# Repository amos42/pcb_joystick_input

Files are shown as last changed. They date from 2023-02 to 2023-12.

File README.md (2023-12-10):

# Arcade Joystick 입력 장치

---

[74HC165를 사용한 Arcade Joystick 입력 보드 (DIP. 1P Ver.)](joystick_74hc165_input_1p/)
([README.md](joystick_74hc165_input_1p/README.md))

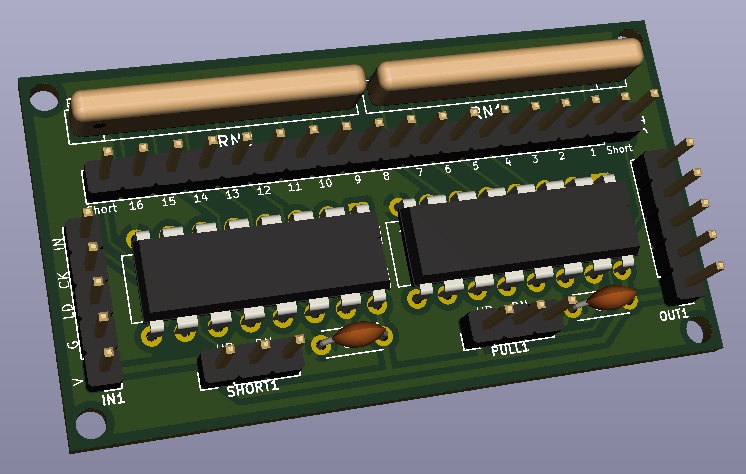
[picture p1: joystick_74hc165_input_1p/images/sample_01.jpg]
joystick-input (DIP Ver.)


---

[74HC165를 사용한 Arcade Joystick 입력 보드 (DIP. 2P Ver.)](joystick_74hc165_input/)
([README.md](joystick_74hc165_input/README.md))

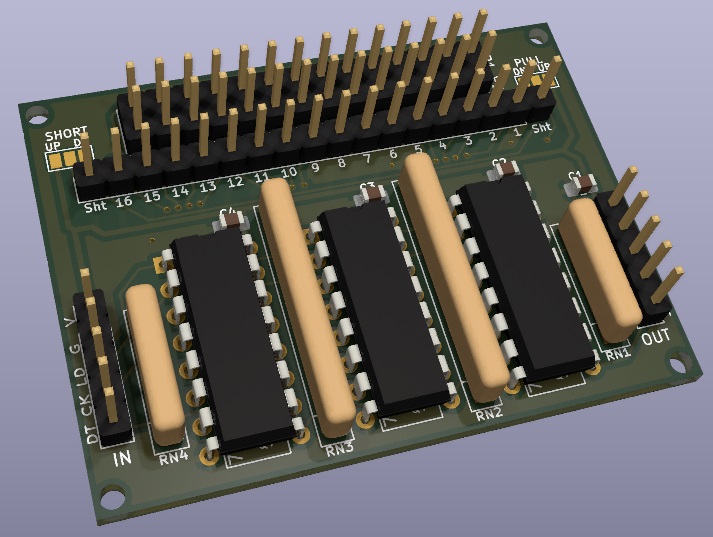
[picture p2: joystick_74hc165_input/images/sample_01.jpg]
joystick-input (DIP Ver.)


---

[74HC165를 사용한 Arcade Joystick 입력 보드 (SMD. 2P Ver.)](joystick_74hc165_input_smd/)
([README.md](joystick_74hc165_input_smd/README.md))

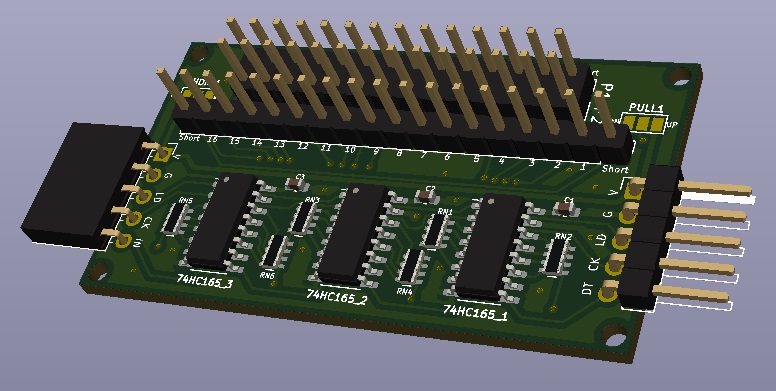
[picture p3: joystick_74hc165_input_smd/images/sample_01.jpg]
joystick-input (SMD Ver.)


---

[74HC165를 사용한 Arcade Joystick 입력 보드 (JST 커넥터. 2P Ver)](joystick_74hc165_input_jst/)
([README.md](joystick_74hc165_input_jst/README.md))

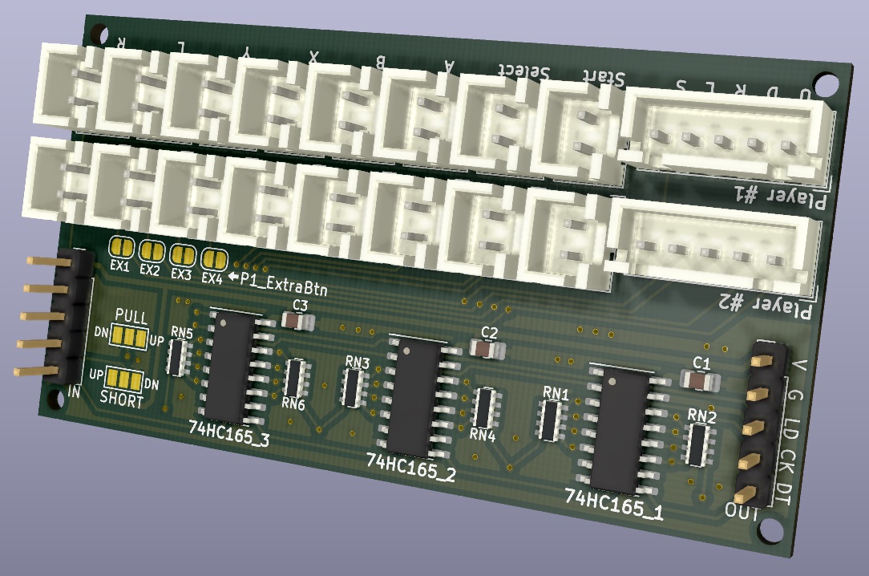
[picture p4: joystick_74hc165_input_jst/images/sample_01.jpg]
joystick-input (JST Ver.)


---

[Raspberry Pie GPIO 입력 모듈](joystick_gpio_input/)
([README.md](joystick_gpio_input/README.md))

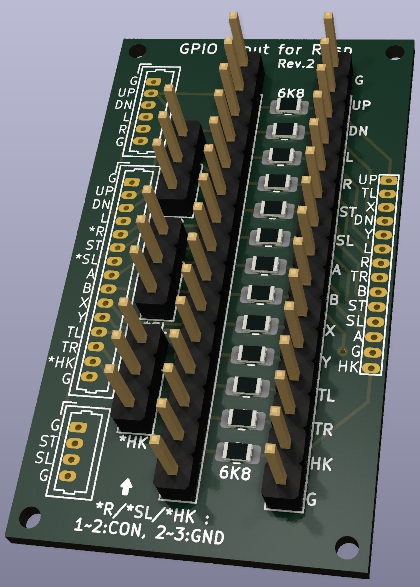
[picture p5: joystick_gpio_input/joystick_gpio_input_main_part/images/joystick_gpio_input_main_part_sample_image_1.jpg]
joystick_gpio_input (main part)


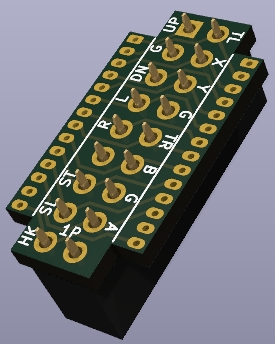
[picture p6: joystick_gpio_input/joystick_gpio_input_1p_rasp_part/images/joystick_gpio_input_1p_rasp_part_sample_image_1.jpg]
joystick_gpio_input (1p part)

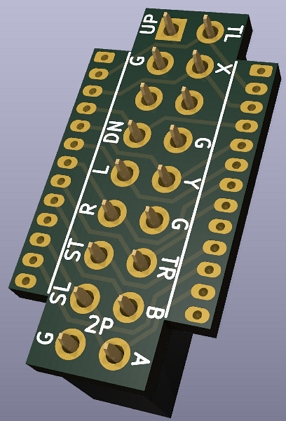
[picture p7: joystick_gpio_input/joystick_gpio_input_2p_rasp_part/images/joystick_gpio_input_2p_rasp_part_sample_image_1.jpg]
joystick_gpio_input (2p part)


---

[Arcade 입력 패널 Support 보드](arcade_input_panel_support/)
([README.md](arcade_input_panel_support/README.md))

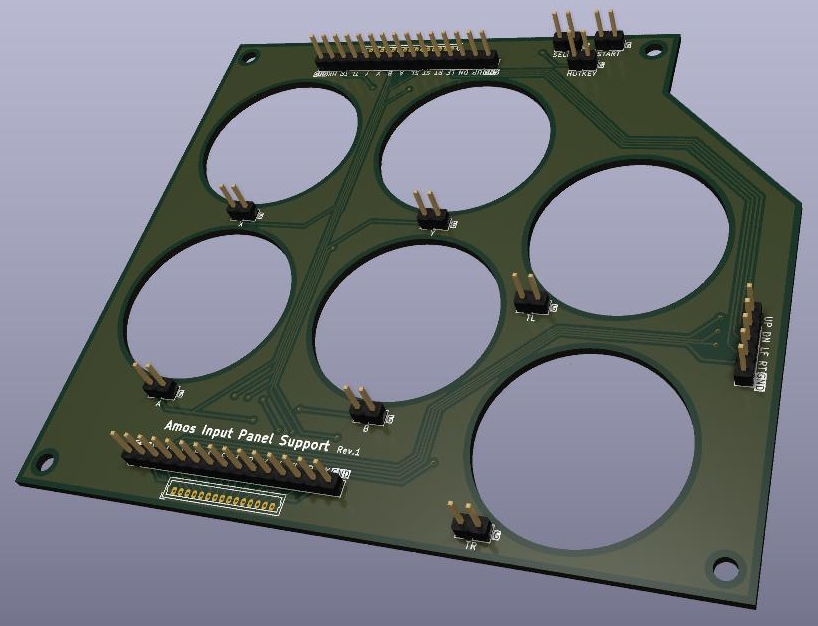
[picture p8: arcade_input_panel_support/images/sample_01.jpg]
Arcade 입력 패널 Support 보드


---

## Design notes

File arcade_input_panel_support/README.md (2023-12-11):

# Arcade Input Panel Support Board

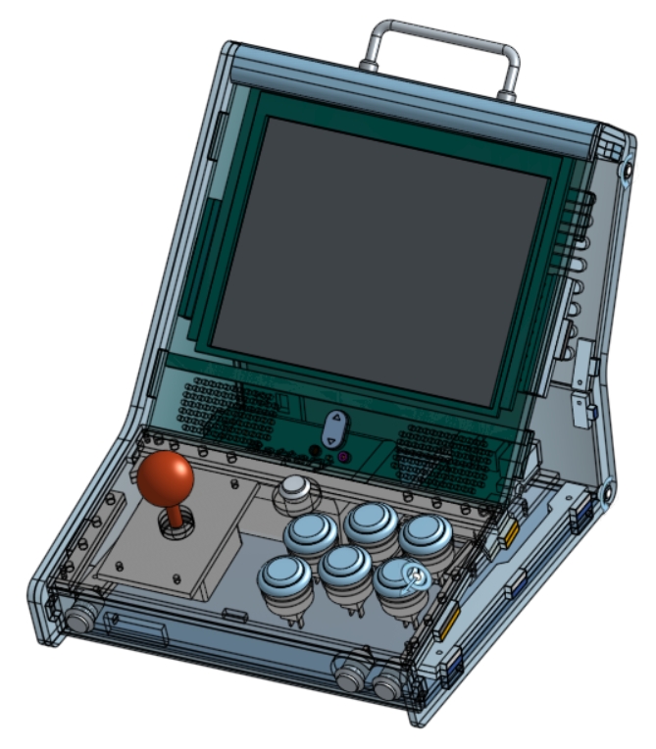
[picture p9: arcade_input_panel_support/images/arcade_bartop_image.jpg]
Bartop 게임기 이미지


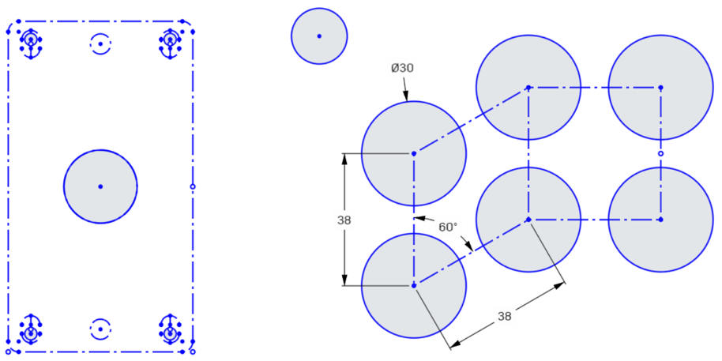
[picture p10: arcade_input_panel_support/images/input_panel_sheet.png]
입력 패널 도면


회로도

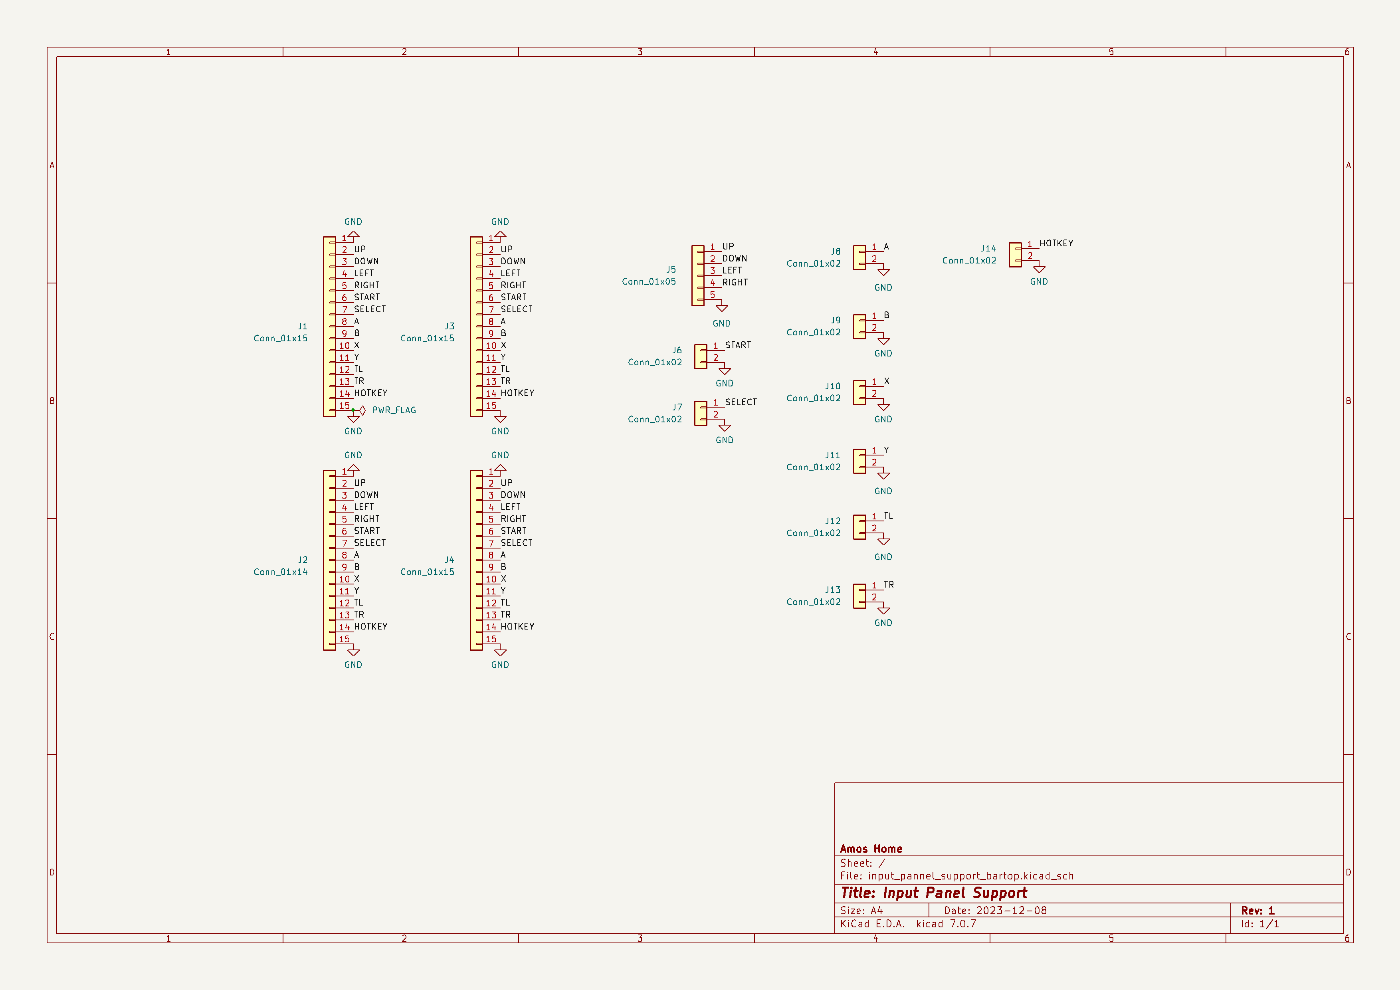
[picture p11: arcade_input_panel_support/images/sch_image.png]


PCB

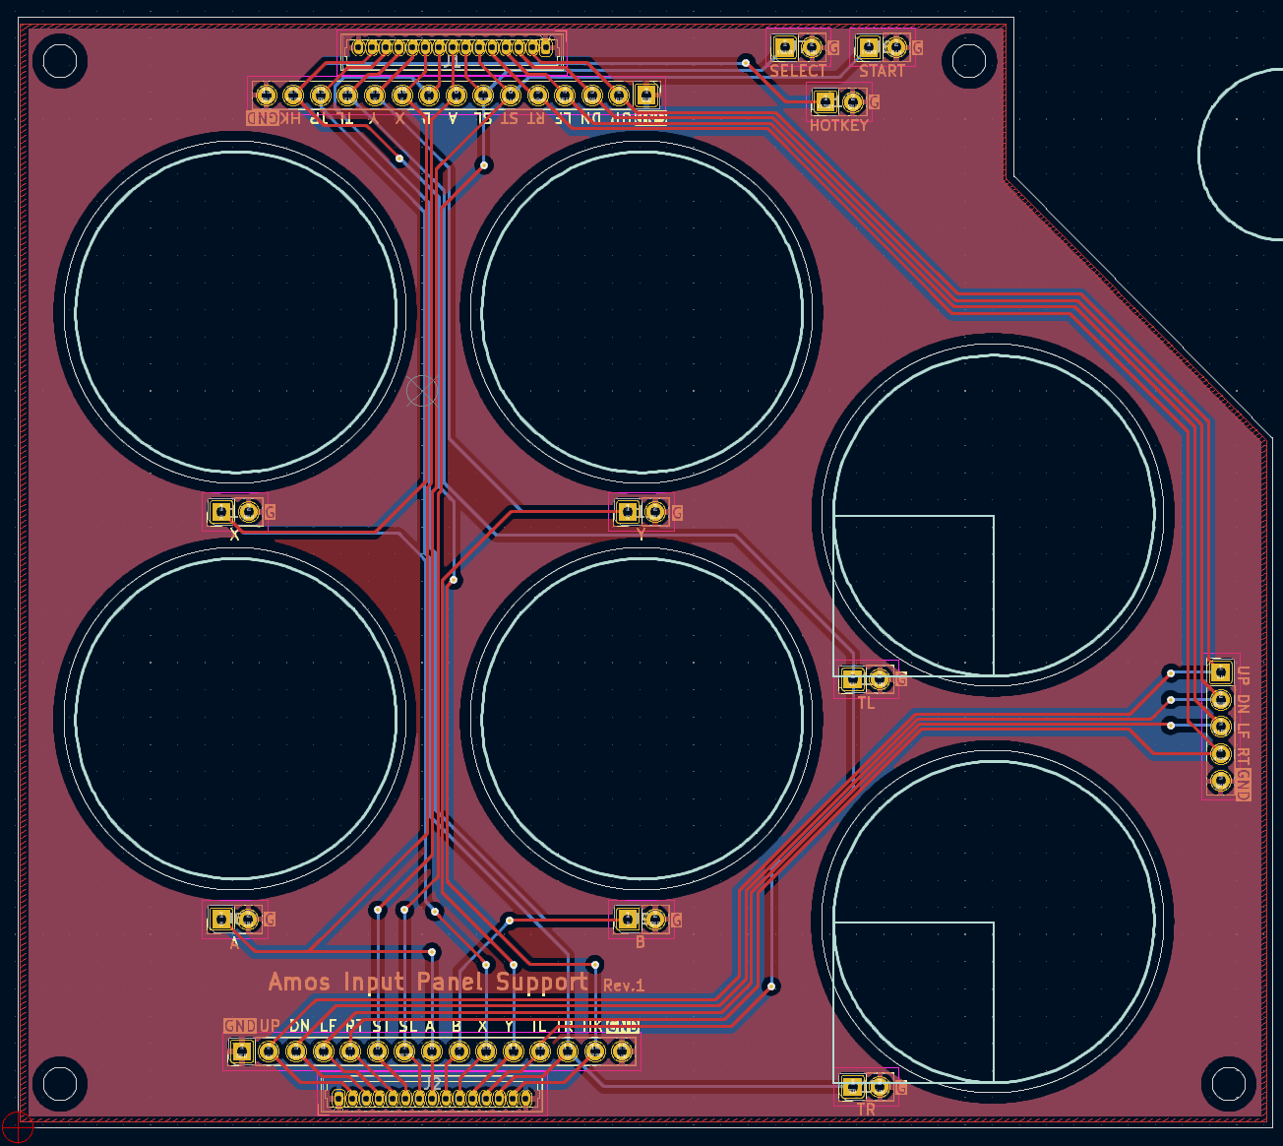
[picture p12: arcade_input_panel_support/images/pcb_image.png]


PCB 샘플 이미지

샘플 앞면

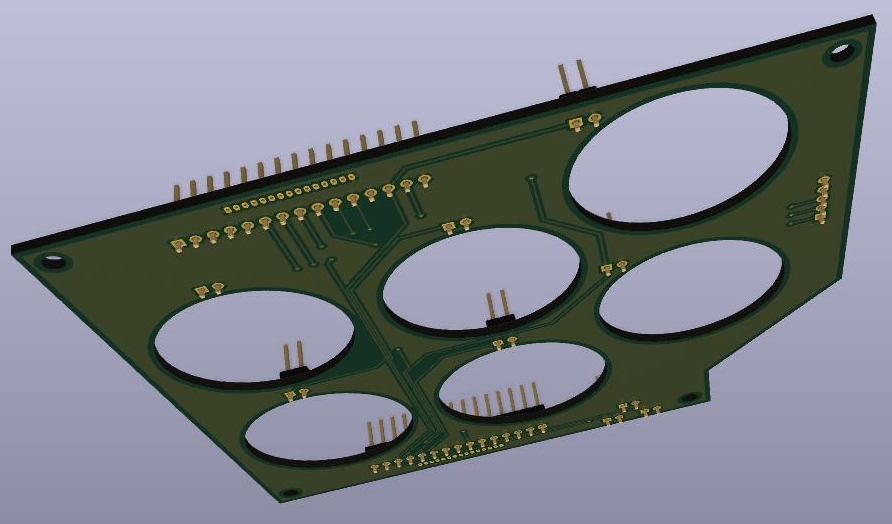
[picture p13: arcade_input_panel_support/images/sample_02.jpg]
샘플 뒷면


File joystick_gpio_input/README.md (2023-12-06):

# Raspberry Pie GPIO 입력 모듈

GPIO 보호 기능을 갖는 입력 모듈

---
am_joyin 혹은 mk_arcade_joystick_rpi의 GPIO 입력 맵을 기본으로 했다.

am_joyin 드라이버도 해당 GPIO 입력 맵과 호환된다.

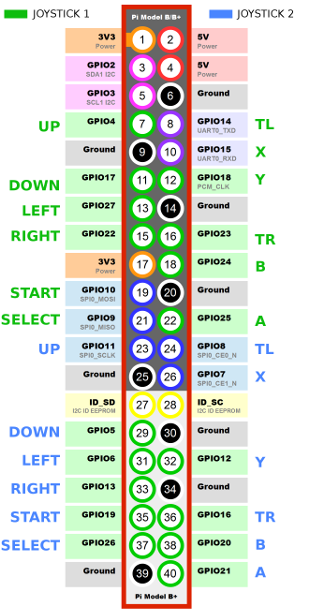
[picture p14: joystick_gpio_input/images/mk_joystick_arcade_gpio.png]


기본적으로는 1P를 기준으로 했으며, 2P 용으로는 GPIO를 모두 소진한다는 문제 때문에 2P는 optional 하게 추가 지원하도록 했다.

1P의 경우, HK를 GPIO11로 사용하게 했는데, 이를 원활히 사용하려면 am_joyin 드라이버를 쓰면 된다.

> ***info***  
am_joyin 링크 : [https://github.com/amos42/am_joyin](https://github.com/amos42/am_joyin)

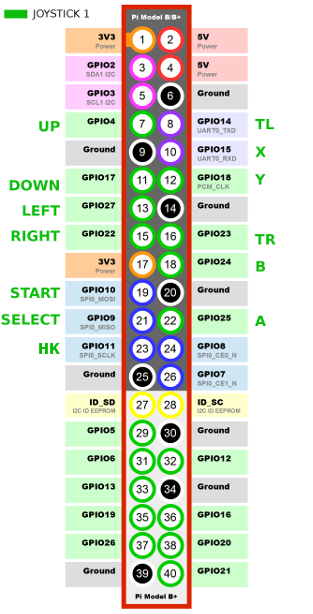
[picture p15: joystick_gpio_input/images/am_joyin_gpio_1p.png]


## 메인 파트

### 회로도

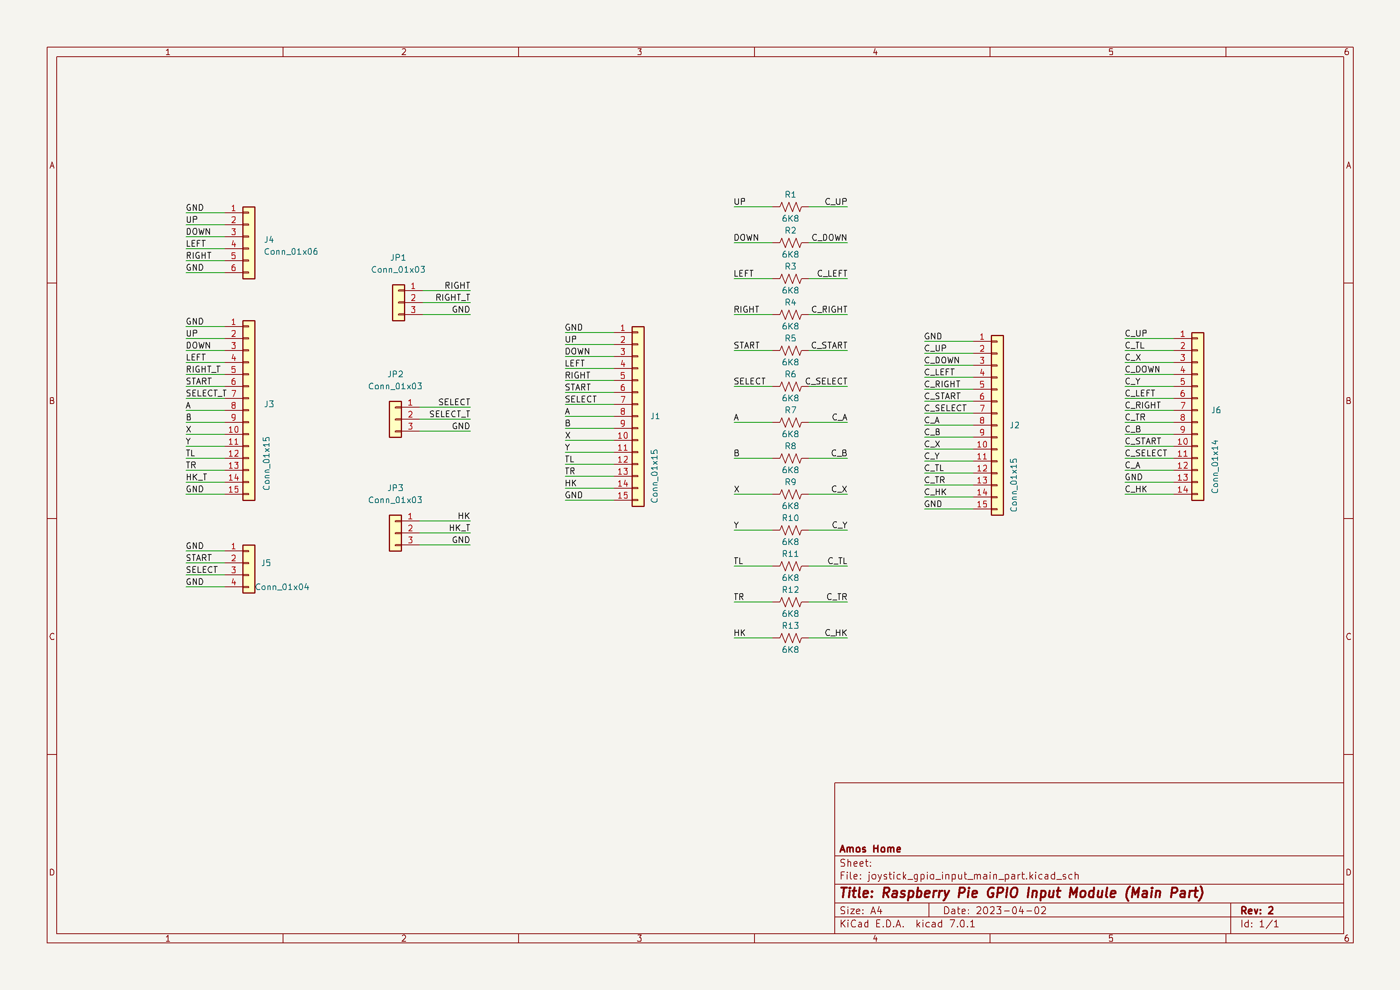
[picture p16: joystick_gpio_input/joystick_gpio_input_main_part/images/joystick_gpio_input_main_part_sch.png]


### PCB

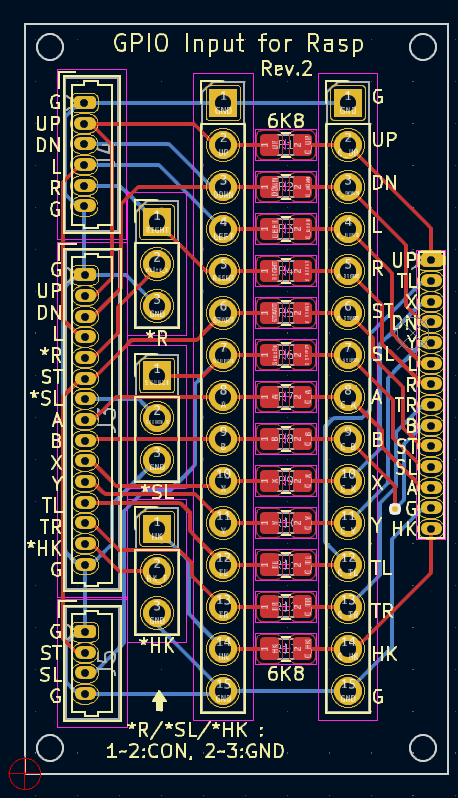
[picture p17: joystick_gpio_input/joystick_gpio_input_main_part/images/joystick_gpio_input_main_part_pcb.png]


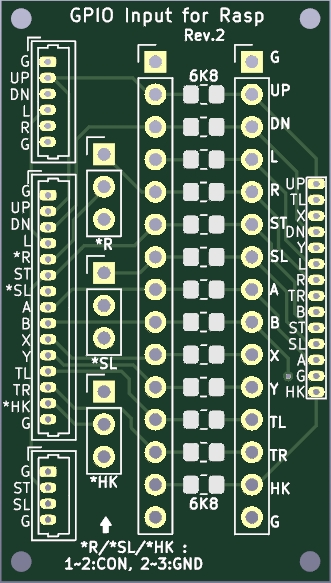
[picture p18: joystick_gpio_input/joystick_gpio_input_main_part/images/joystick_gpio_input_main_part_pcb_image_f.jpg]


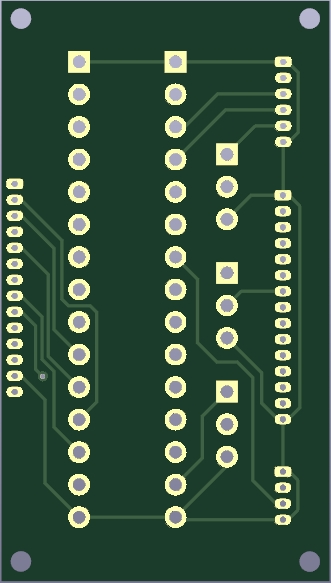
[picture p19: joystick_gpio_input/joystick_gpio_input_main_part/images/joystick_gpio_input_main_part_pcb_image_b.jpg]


### BOM

| Designator | Package | Quantity | Designation |
|---|---|---|---|
| R1~R13 | R_0805_2012Metric | 13 | 6.8K |

### 샘플 이미지

PCB

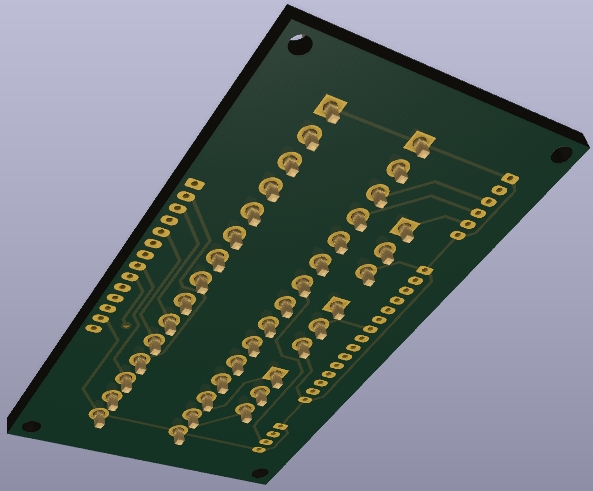
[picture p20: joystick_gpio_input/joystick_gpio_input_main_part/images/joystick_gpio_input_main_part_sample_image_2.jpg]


---

## Raspberry Pi Connector 1P 파트

### 회로도

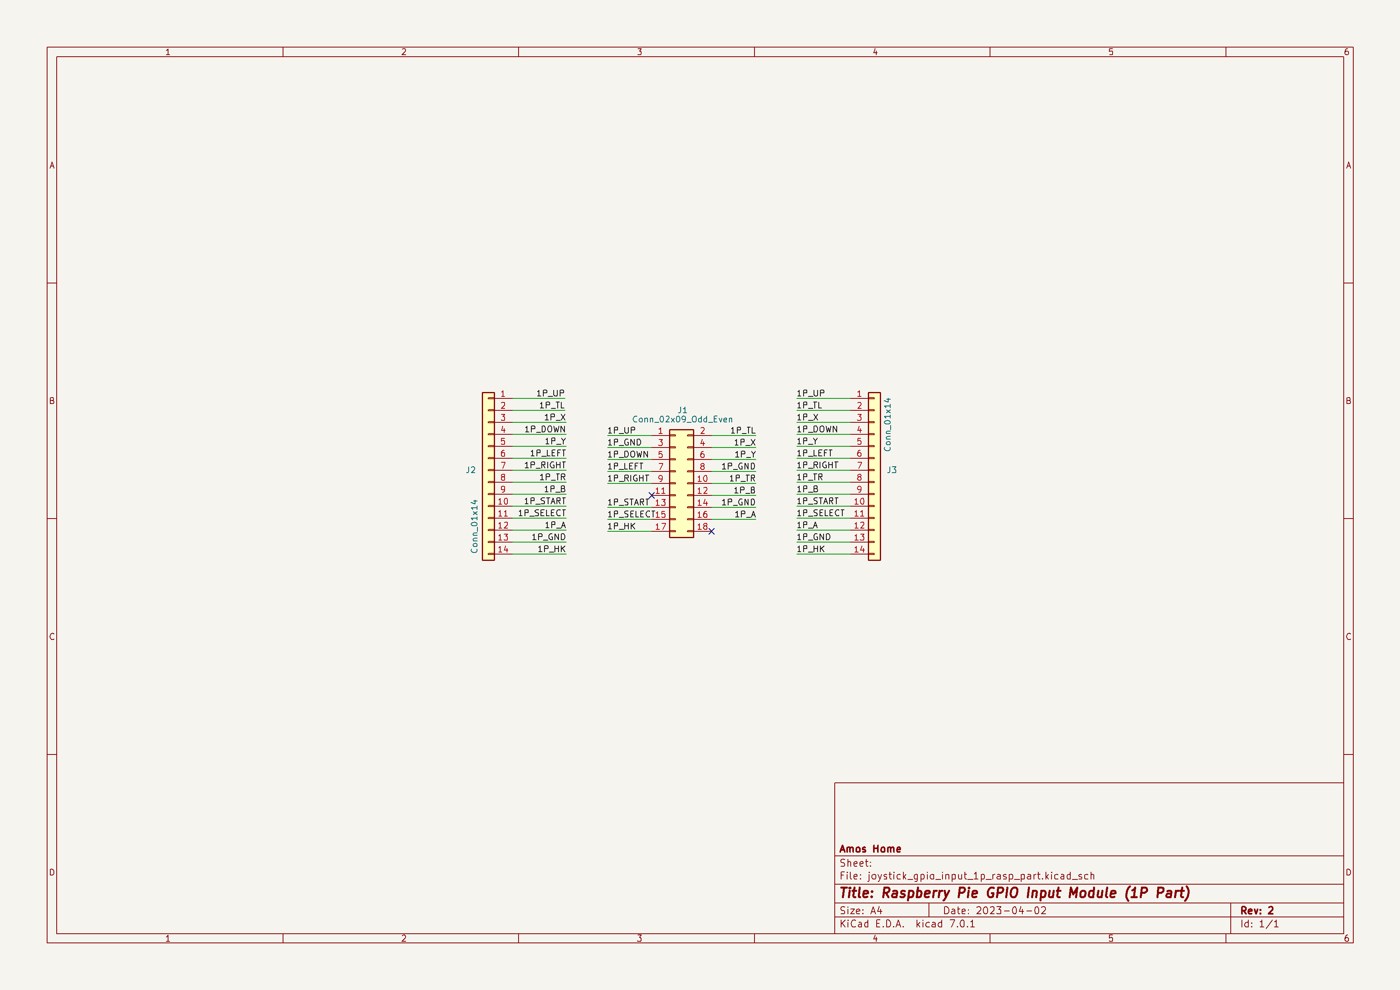
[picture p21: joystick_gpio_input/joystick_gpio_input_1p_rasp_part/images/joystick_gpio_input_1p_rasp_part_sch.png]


### PCB

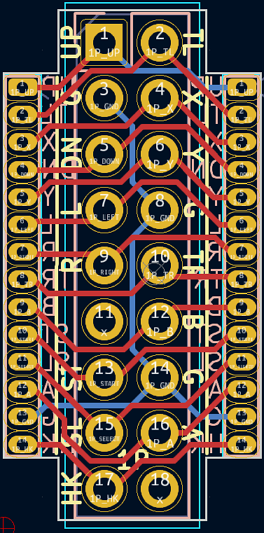
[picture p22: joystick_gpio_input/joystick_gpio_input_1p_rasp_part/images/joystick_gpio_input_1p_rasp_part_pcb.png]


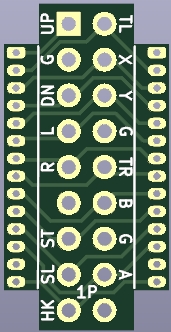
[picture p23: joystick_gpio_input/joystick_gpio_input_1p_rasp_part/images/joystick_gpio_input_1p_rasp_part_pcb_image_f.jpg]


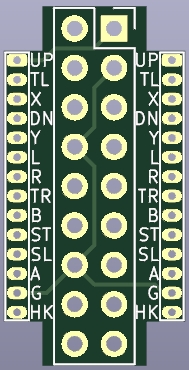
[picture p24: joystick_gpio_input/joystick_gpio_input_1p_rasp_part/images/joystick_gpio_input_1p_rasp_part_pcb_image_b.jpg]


### 샘플 이미지

PCB

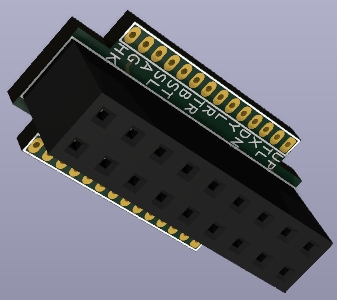
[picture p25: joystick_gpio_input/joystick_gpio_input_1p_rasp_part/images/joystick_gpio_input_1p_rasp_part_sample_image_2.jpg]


---

## Raspberry Pi Connector 2p 파트

### 회로도

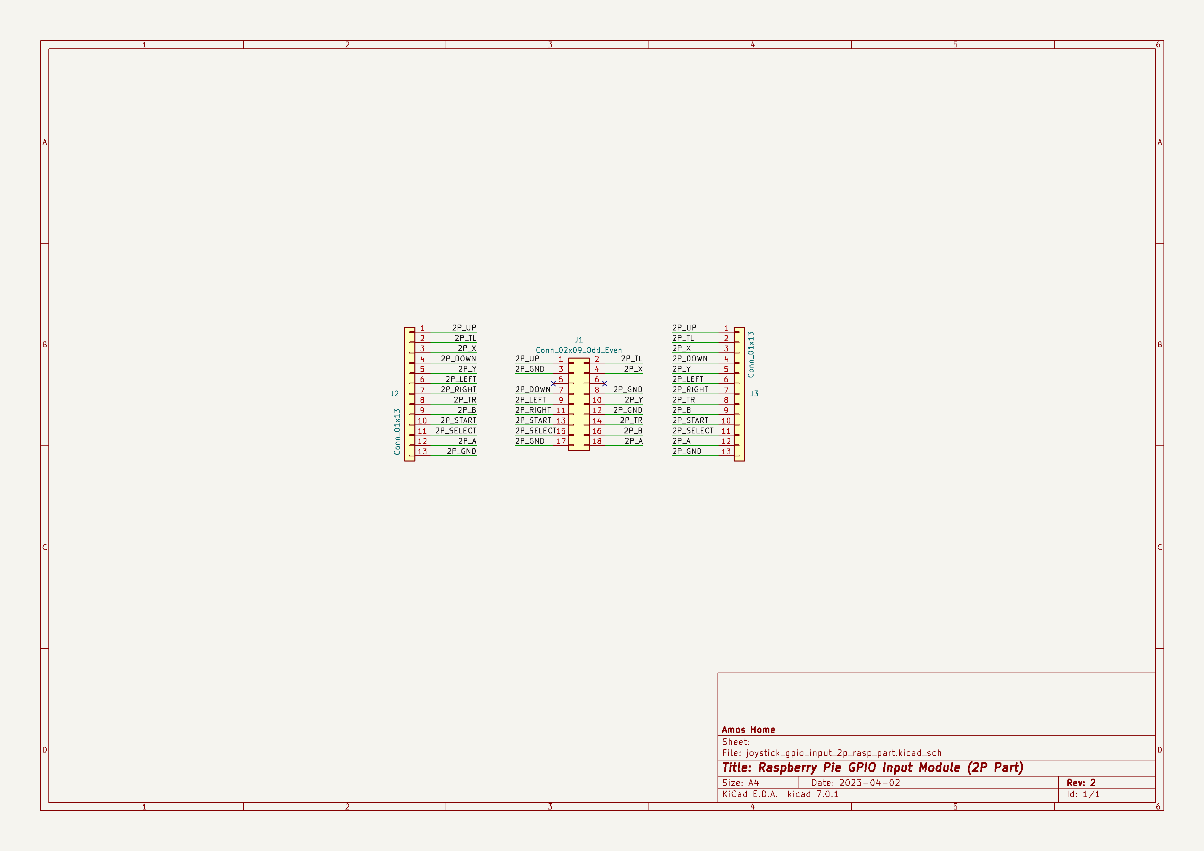
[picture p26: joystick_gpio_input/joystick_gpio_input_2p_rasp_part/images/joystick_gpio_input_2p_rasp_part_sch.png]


### PCB

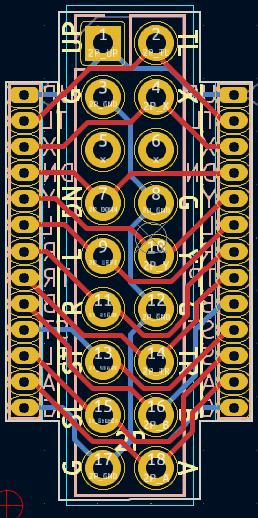
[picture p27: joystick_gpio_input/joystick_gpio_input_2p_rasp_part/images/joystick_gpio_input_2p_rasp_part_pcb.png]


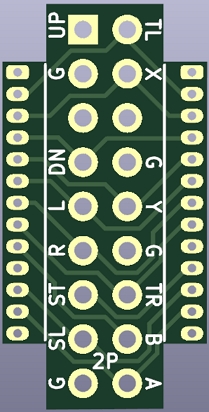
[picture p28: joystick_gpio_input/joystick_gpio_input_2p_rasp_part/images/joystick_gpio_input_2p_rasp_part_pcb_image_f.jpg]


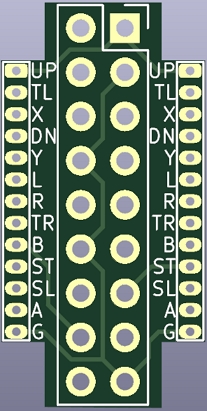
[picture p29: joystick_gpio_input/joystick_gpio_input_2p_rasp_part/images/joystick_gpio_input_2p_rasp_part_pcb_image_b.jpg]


### 샘플 이미지

PCB

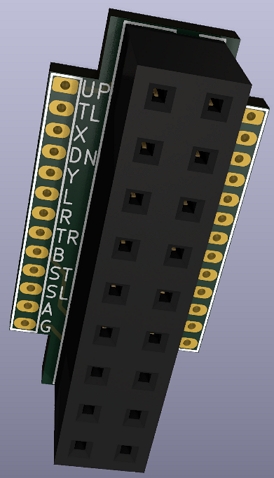
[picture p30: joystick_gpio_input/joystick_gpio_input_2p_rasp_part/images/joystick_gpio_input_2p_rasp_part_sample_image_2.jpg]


## 점퍼 세팅

커넥터 중 J3는 일부 핀을 점퍼 세팅으로 변경이 가능하다.

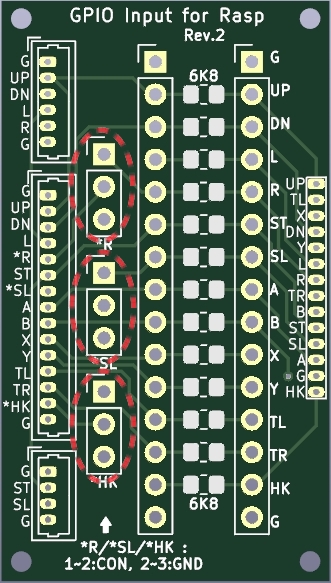
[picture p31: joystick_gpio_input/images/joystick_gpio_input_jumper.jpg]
샘플


* *R - 1-2 끊고 2-3 쇼트시, J3의 Right 핀이 GND로 쇼트
* *SL - 1-2 끊고 2-3 쇼트시, J3의 Select 핀이 GND로 쇼트
* *HK - 1-2 끊고 2-3 쇼트시, J3의 HotKey 핀이 GND로 쇼트

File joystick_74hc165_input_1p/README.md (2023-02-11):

# 74HC165를 이용한 Joystick (1P)입력 보드

회로도

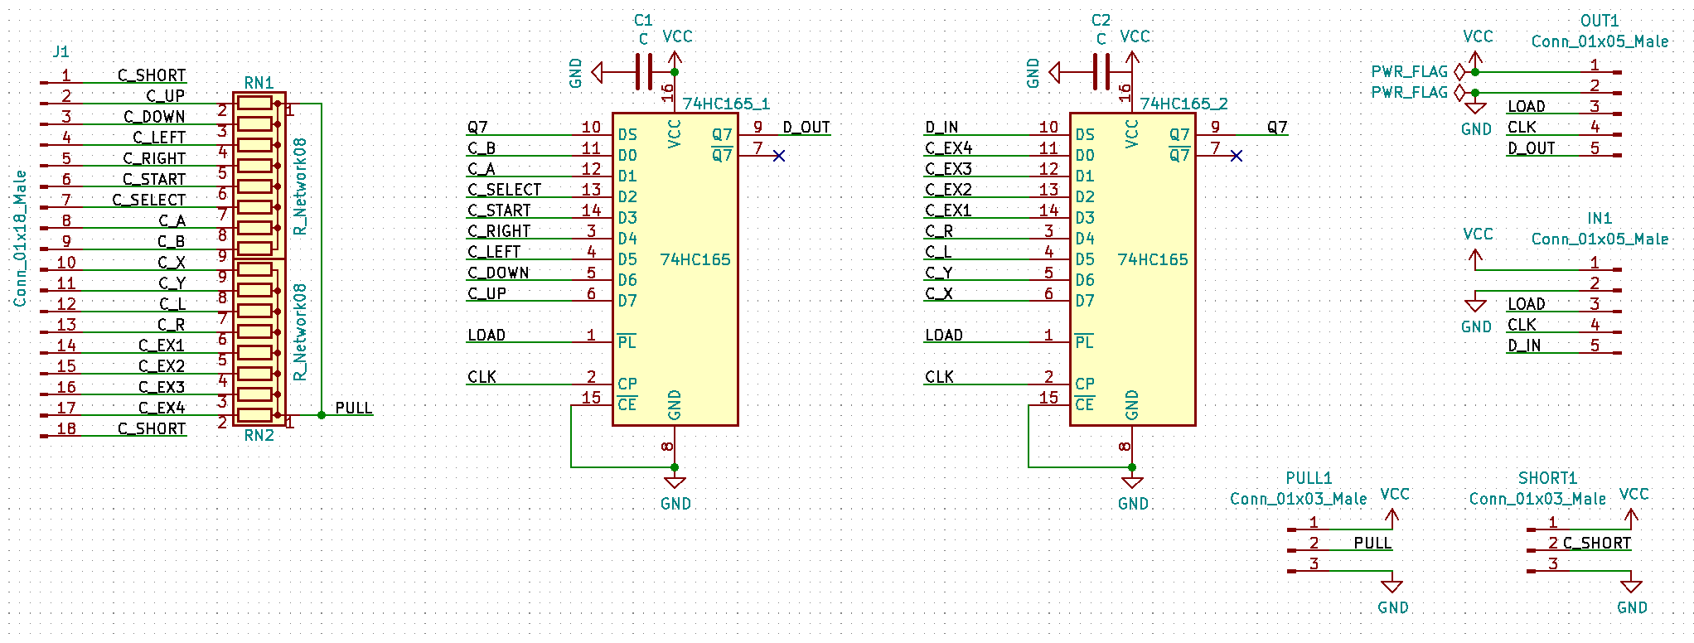
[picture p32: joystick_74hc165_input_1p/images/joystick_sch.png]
회로도


PCB 이미지 앞면

PCB

PCB 이미지 뒷면

PCB

샘플 이미지

샘플

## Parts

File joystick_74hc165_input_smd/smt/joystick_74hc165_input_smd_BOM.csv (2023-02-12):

Designator | Footprint | Comment
RN2,RN1,RN4,RN5,RN3,RN6 | R_Array_Concave_4x0603 | 10K | C29718
C1,C2,C3 | C_0805_2012Metric_Pad1.18x1.45mm_HandSolder | 100nF
74HC165_1,74HC165_2,74HC165_3 | SOIC-16_3.9x9.9mm_P1.27mm | 74HC165
C4 | C_0805_2012Metric_Pad1.18x1.45mm_HandSolder | 22nF

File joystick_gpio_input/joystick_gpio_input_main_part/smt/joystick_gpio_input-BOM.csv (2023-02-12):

Designator | Footprint | Comment
R10,R12,R13,R11,R4,R9,R5,R2,R8,R3,R7,R6,R1 | R_0805_2012Metric_Pad1.20x1.40mm_HandSolder | 6K8

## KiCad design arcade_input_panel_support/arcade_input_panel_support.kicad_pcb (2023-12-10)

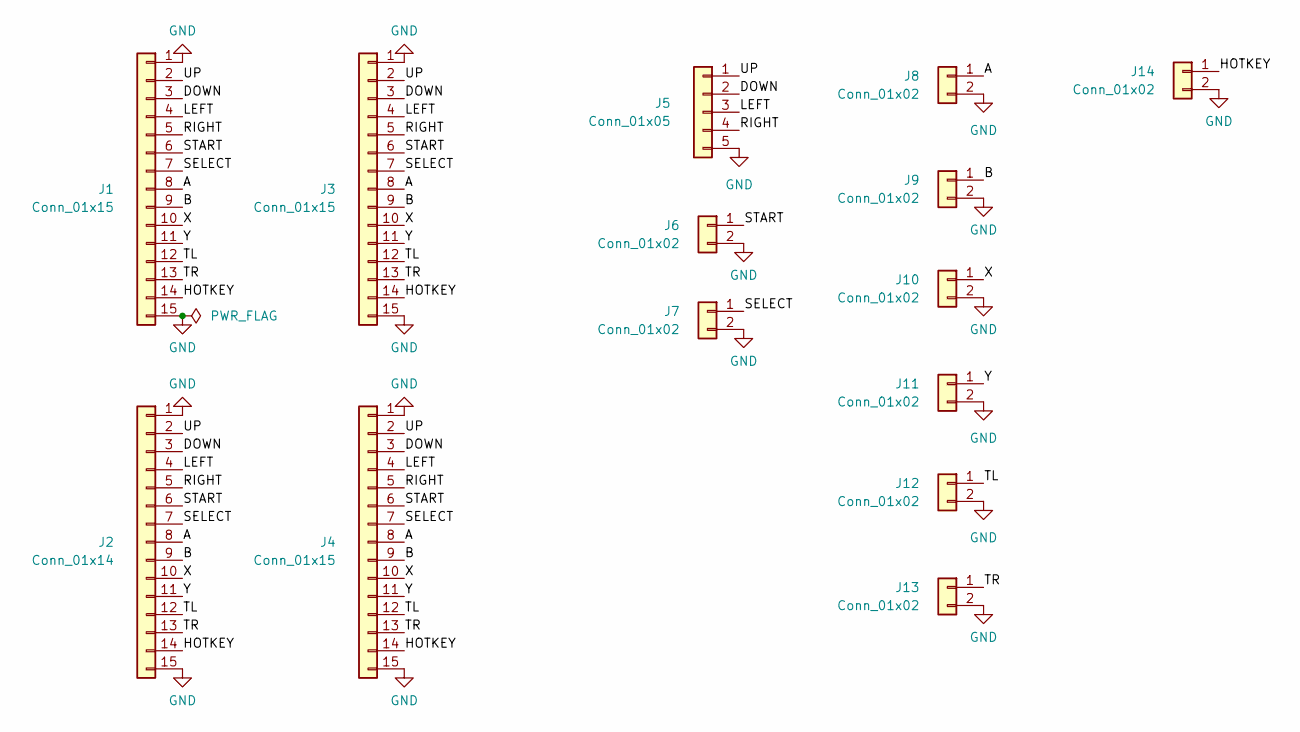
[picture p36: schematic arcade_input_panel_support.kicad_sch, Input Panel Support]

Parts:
J1: Conn_01x15; Molex_PicoBlade_53047-1510_1x15_P1.25mm_Vertical
J2: Conn_01x14; Molex_PicoBlade_53047-1510_1x15_P1.25mm_Vertical
J3, J4: Conn_01x15; PinHeader_1x15_P2.54mm_Vertical
J5: Conn_01x05; PinHeader_1x05_P2.54mm_Vertical
J6, J7, J8, J9, J10, J11, J12, J13, J14: Conn_01x02; PinHeader_1x02_P2.54mm_Vertical

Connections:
/A: J1.8, J2.8, J3.8, J4.8, J8.1
/B: J1.9, J2.9, J3.9, J4.9, J9.1
/DOWN: J1.3, J2.3, J3.3, J4.3, J5.2
/HOTKEY: J1.14, J2.14, J3.14, J4.14, J14.1
/LEFT: J1.4, J2.4, J3.4, J4.4, J5.3
/RIGHT: J1.5, J2.5, J3.5, J4.5, J5.4
/SELECT: J1.7, J2.7, J3.7, J4.7, J7.1
/START: J1.6, J2.6, J3.6, J4.6, J6.1
/TL: J1.12, J2.12, J3.12, J4.12, J12.1
/TR: J1.13, J2.13, J3.13, J4.13, J13.1
/UP: J1.2, J2.2, J3.2, J4.2, J5.1
/X: J1.10, J2.10, J3.10, J4.10, J10.1
/Y: J1.11, J2.11, J3.11, J4.11, J11.1
GND: J1.1, J1.15, J2.1, J2.15, J3.1, J3.15, J4.1, J4.15, J5.5, J6.2, J7.2, J8.2, J9.2, J10.2, J11.2, J12.2, J13.2, J14.2

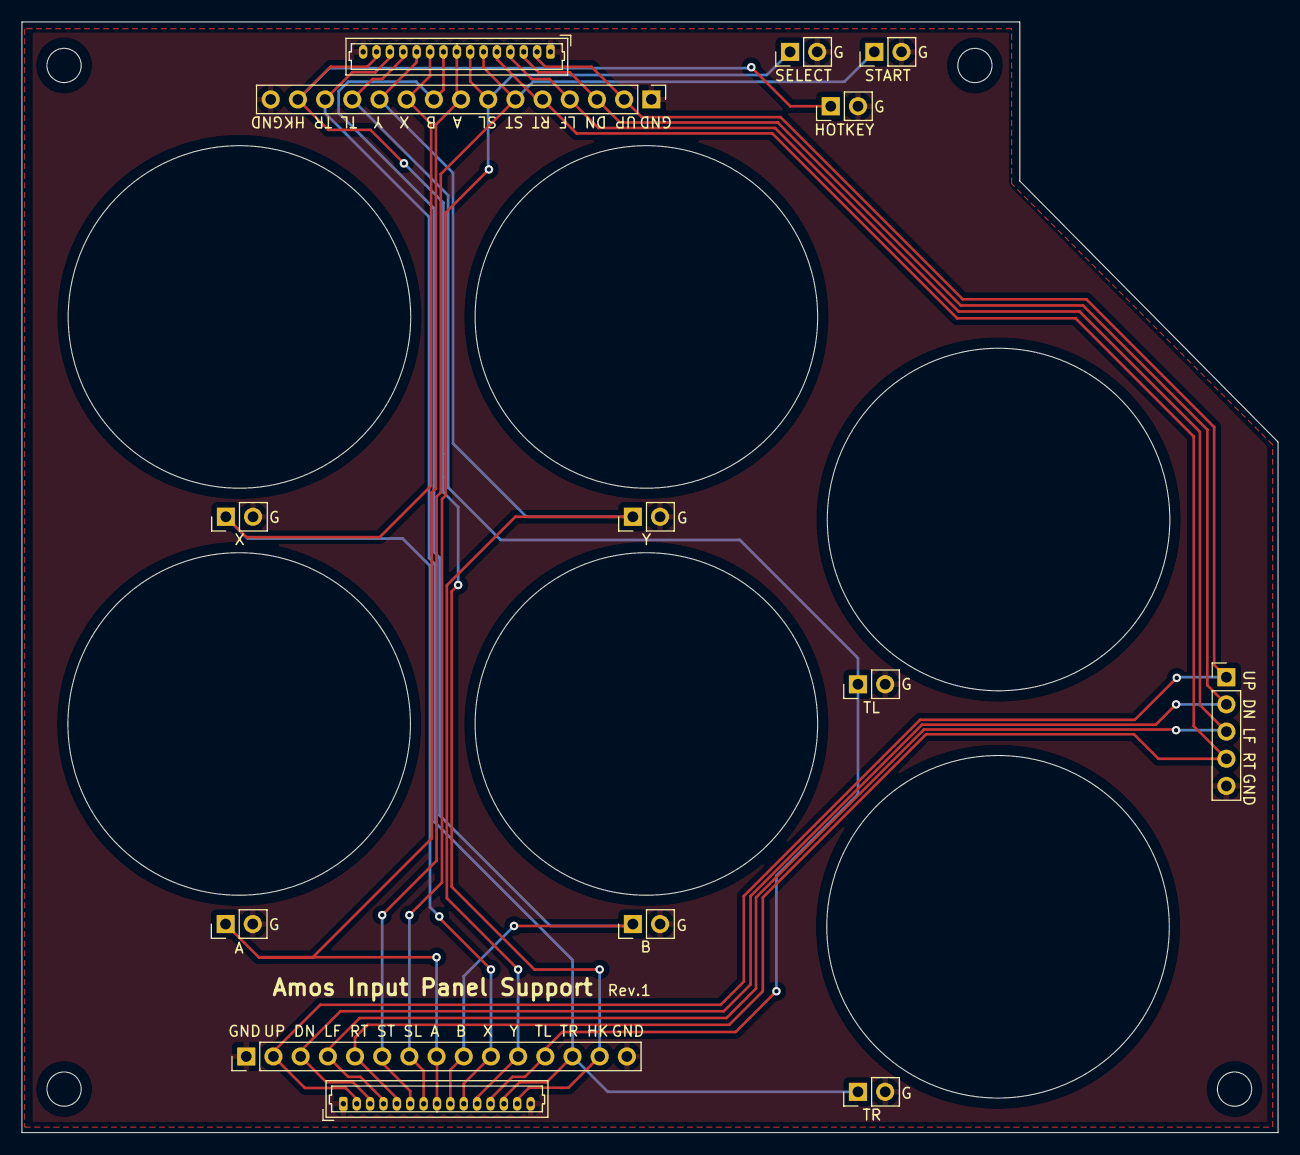
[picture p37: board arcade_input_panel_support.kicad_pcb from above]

Board: 2 copper layers, 117.3 x 103.8 mm, 14 parts (0 on the bottom side), 14 nets.

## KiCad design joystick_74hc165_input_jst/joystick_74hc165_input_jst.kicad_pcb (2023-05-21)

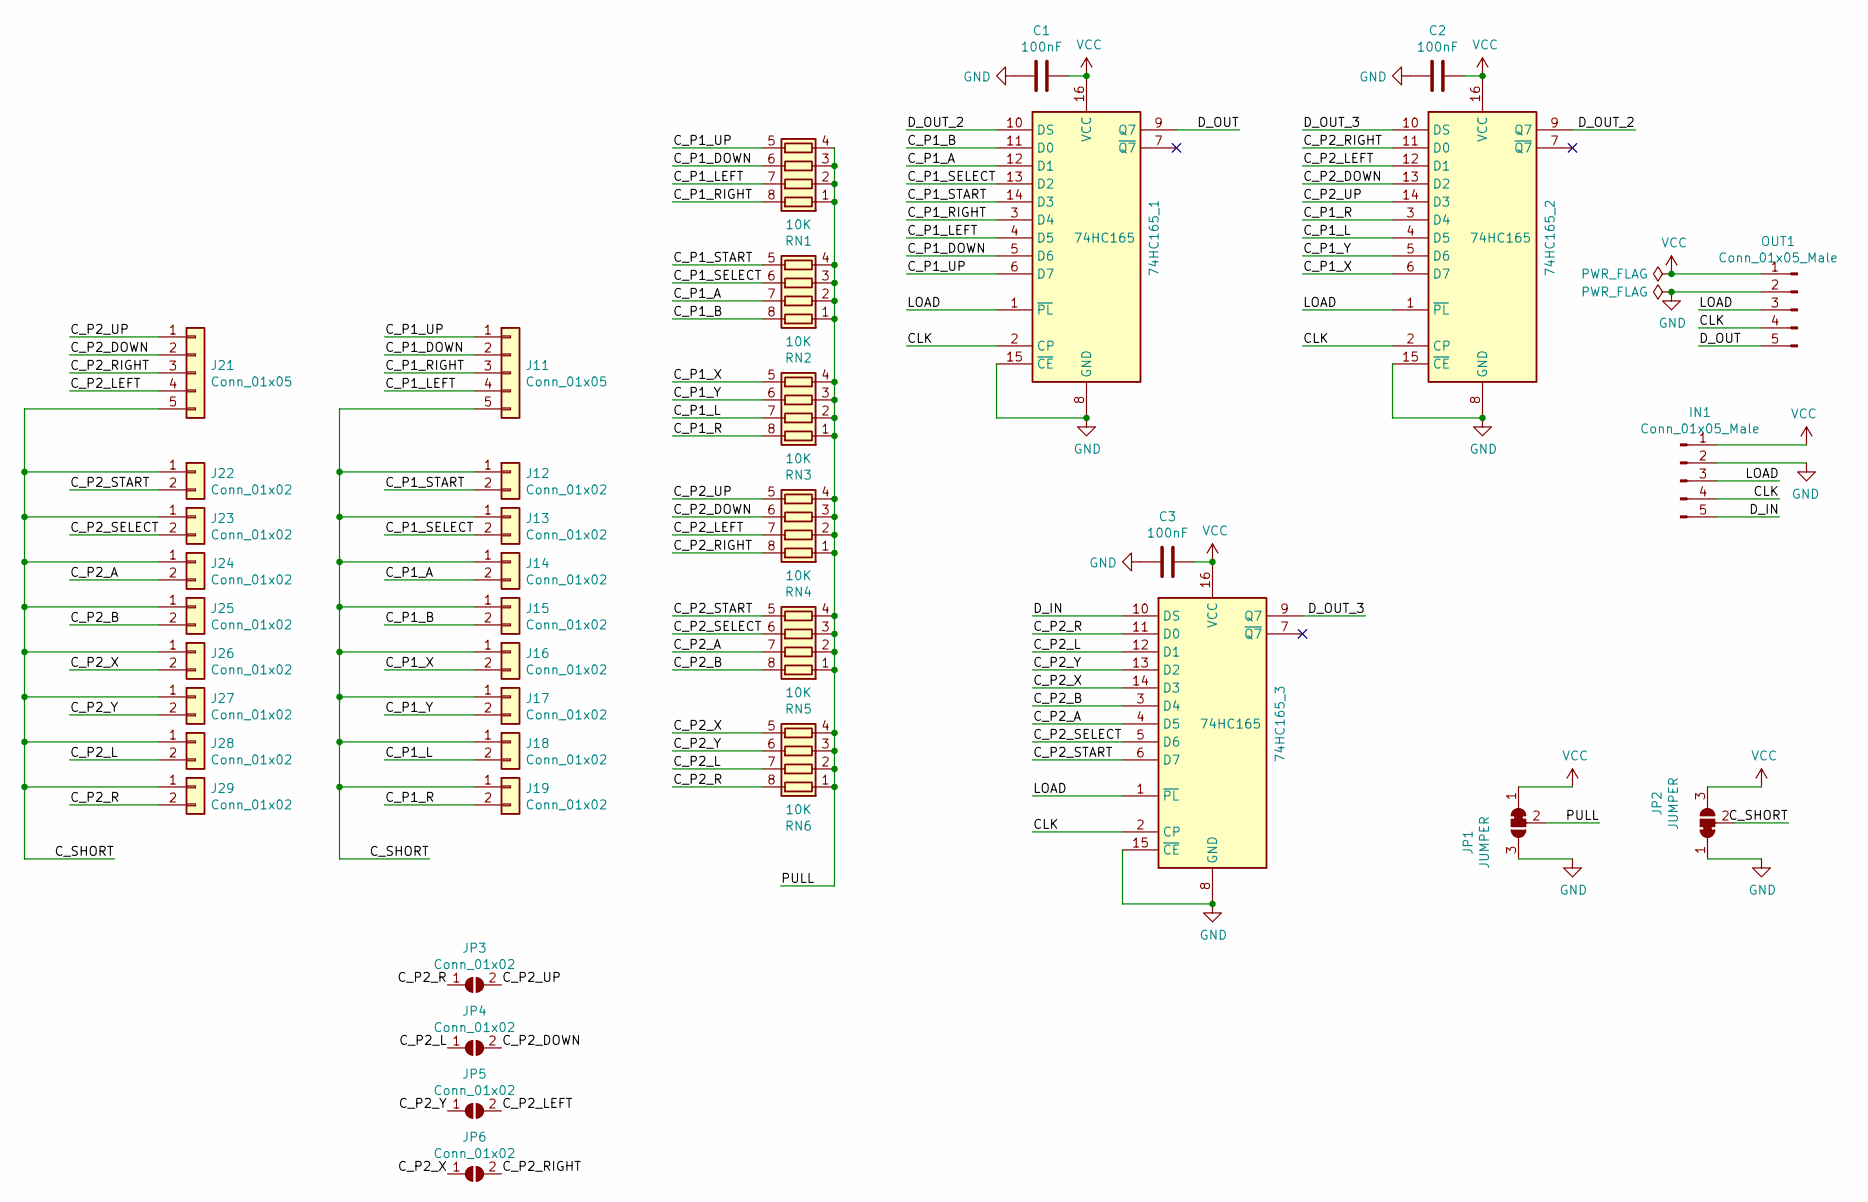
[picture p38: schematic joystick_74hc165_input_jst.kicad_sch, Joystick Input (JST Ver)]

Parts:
74HC165_1, 74HC165_2, 74HC165_3: 74HC165; SOIC-16_3.9x9.9mm_P1.27mm
C1, C2, C3: 100nF; C_0805_2012Metric_Pad1.18x1.45mm_HandSolder
IN1: Conn_01x05_Male; PinHeader_1x05_P2.54mm_Vertical
J11, J21: Conn_01x05; JST_XH_B5B-XH-A_1x05_P2.50mm_Vertical
J12, J13, J14, J15, J16, J17, J18, J19, J22, J23, J24, J25, J26, J27, J28, J29: Conn_01x02; JST_XH_B2B-XH-A_1x02_P2.50mm_Vertical
JP1, JP2: JUMPER; SolderJumper-3_P1.3mm_Bridged12_Pad1.0x1.5mm_NumberLabels
JP3, JP4, JP5, JP6: Conn_01x02; SolderJumper-2_P1.3mm_Bridged_RoundedPad1.0x1.5mm
OUT1: Conn_01x05_Male; PinHeader_1x05_P2.54mm_Vertical
RN1, RN2, RN3, RN4, RN5, RN6: 10K; R_Array_Concave_4x0603

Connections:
/CLK: 74HC165_1.2 (CP), 74HC165_2.2 (CP), 74HC165_3.2 (CP), IN1.4, OUT1.4
/C_P1_A: 74HC165_1.12 (D1), J14.2, RN2.7 (R2.2)
/C_P1_B: 74HC165_1.11 (D0), J15.2, RN2.8 (R1.2)
/C_P1_DOWN: 74HC165_1.5 (D6), J11.2, RN1.6 (R3.2)
/C_P1_L: 74HC165_2.4 (D5), J18.2, RN3.7 (R2.2)
/C_P1_LEFT: 74HC165_1.4 (D5), J11.4, RN1.7 (R2.2)
/C_P1_R: 74HC165_2.3 (D4), J19.2, RN3.8 (R1.2)
/C_P1_RIGHT: 74HC165_1.3 (D4), J11.3, RN1.8 (R1.2)
/C_P1_SELECT: 74HC165_1.13 (D2), J13.2, RN2.6 (R3.2)
/C_P1_START: 74HC165_1.14 (D3), J12.2, RN2.5 (R4.2)
/C_P1_UP: 74HC165_1.6 (D7), J11.1, RN1.5 (R4.2)
/C_P1_X: 74HC165_2.6 (D7), J16.2, RN3.5 (R4.2)
/C_P1_Y: 74HC165_2.5 (D6), J17.2, RN3.6 (R3.2)
/C_P2_A: 74HC165_3.4 (D5), J24.2, RN5.7 (R2.2)
/C_P2_B: 74HC165_3.3 (D4), J25.2, RN5.8 (R1.2)
/C_P2_DOWN: 74HC165_2.13 (D2), J21.2, JP4.2 (B), RN4.6 (R3.2)
/C_P2_L: 74HC165_3.12 (D1), J28.2, JP4.1 (A), RN6.7 (R2.2)
/C_P2_LEFT: 74HC165_2.12 (D1), J21.4, JP5.2 (B), RN4.7 (R2.2)
/C_P2_R: 74HC165_3.11 (D0), J29.2, JP3.1 (A), RN6.8 (R1.2)
/C_P2_RIGHT: 74HC165_2.11 (D0), J21.3, JP6.2 (B), RN4.8 (R1.2)
/C_P2_SELECT: 74HC165_3.5 (D6), J23.2, RN5.6 (R3.2)
/C_P2_START: 74HC165_3.6 (D7), J22.2, RN5.5 (R4.2)
/C_P2_UP: 74HC165_2.14 (D3), J21.1, JP3.2 (B), RN4.5 (R4.2)
/C_P2_X: 74HC165_3.14 (D3), J26.2, JP6.1 (A), RN6.5 (R4.2)
/C_P2_Y: 74HC165_3.13 (D2), J27.2, JP5.1 (A), RN6.6 (R3.2)
/C_SHORT: J11.5, J12.1, J13.1, J14.1, J15.1, J16.1, J17.1, J18.1, J19.1, J21.5, J22.1, J23.1, J24.1, J25.1, J26.1, J27.1, J28.1, J29.1, JP2.2 (C)
/D_IN: 74HC165_3.10 (DS), IN1.5
/D_OUT: 74HC165_1.9 (Q7), OUT1.5
/D_OUT_2: 74HC165_1.10 (DS), 74HC165_2.9 (Q7)
/D_OUT_3: 74HC165_2.10 (DS), 74HC165_3.9 (Q7)
/LOAD: 74HC165_1.1 (~PL), 74HC165_2.1 (~PL), 74HC165_3.1 (~PL), IN1.3, OUT1.3
/PULL: JP1.2 (C), RN1.1 (R1.1), RN1.2 (R2.1), RN1.3 (R3.1), RN1.4 (R4.1), RN2.1 (R1.1), RN2.2 (R2.1), RN2.3 (R3.1), RN2.4 (R4.1), RN3.1 (R1.1), RN3.2 (R2.1), RN3.3 (R3.1), RN3.4 (R4.1), RN4.1 (R1.1), RN4.2 (R2.1), RN4.3 (R3.1), RN4.4 (R4.1), RN5.1 (R1.1), RN5.2 (R2.1), RN5.3 (R3.1), RN5.4 (R4.1), RN6.1 (R1.1), RN6.2 (R2.1), RN6.3 (R3.1), RN6.4 (R4.1)
GND: 74HC165_1.8 (GND), 74HC165_1.15 (~CE), 74HC165_2.8 (GND), 74HC165_2.15 (~CE), 74HC165_3.8 (GND), 74HC165_3.15 (~CE), C1.2, C2.2, C3.2, IN1.2, JP1.3 (B), JP2.1 (A), OUT1.2
VCC: 74HC165_1.16 (VCC), 74HC165_2.16 (VCC), 74HC165_3.16 (VCC), C1.1, C2.1, C3.1, IN1.1, JP1.1 (A), JP2.3 (B), OUT1.1

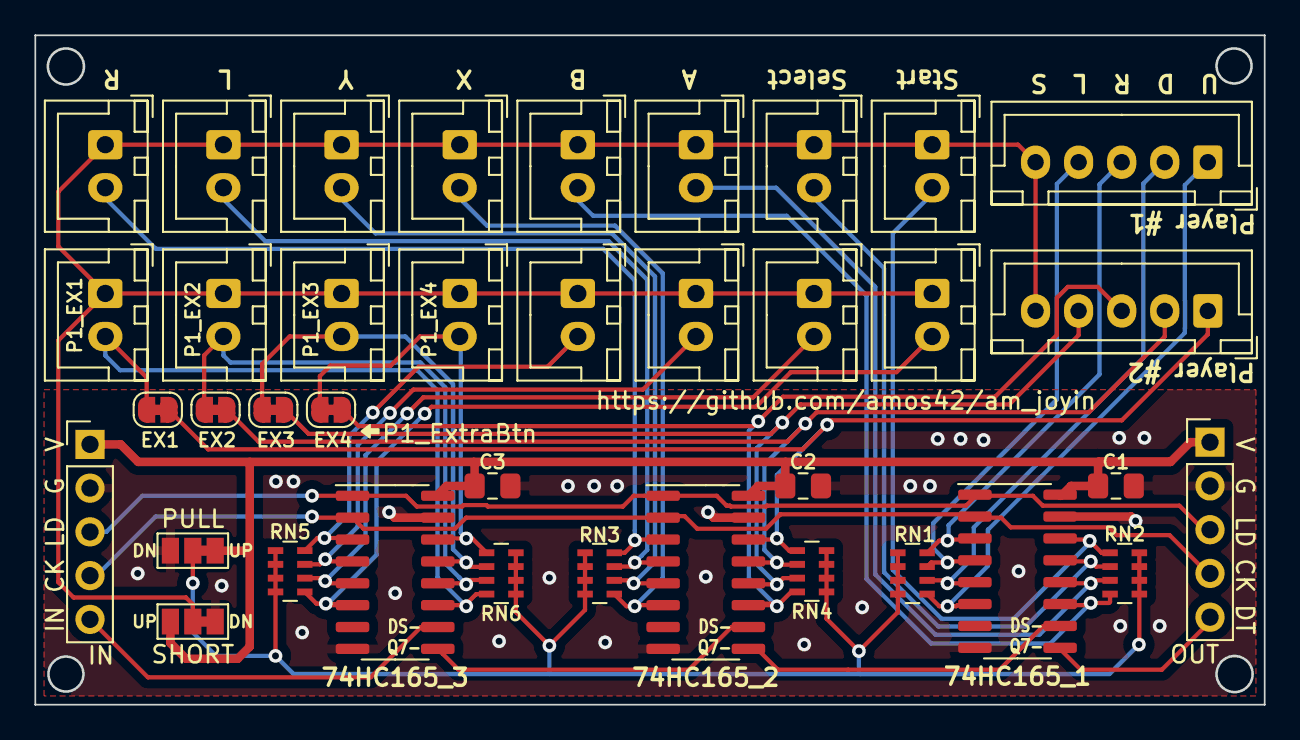
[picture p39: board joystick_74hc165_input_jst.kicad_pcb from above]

Board: 2 copper layers, 71.4 x 38.9 mm, 38 parts (0 on the bottom side), 34 nets.

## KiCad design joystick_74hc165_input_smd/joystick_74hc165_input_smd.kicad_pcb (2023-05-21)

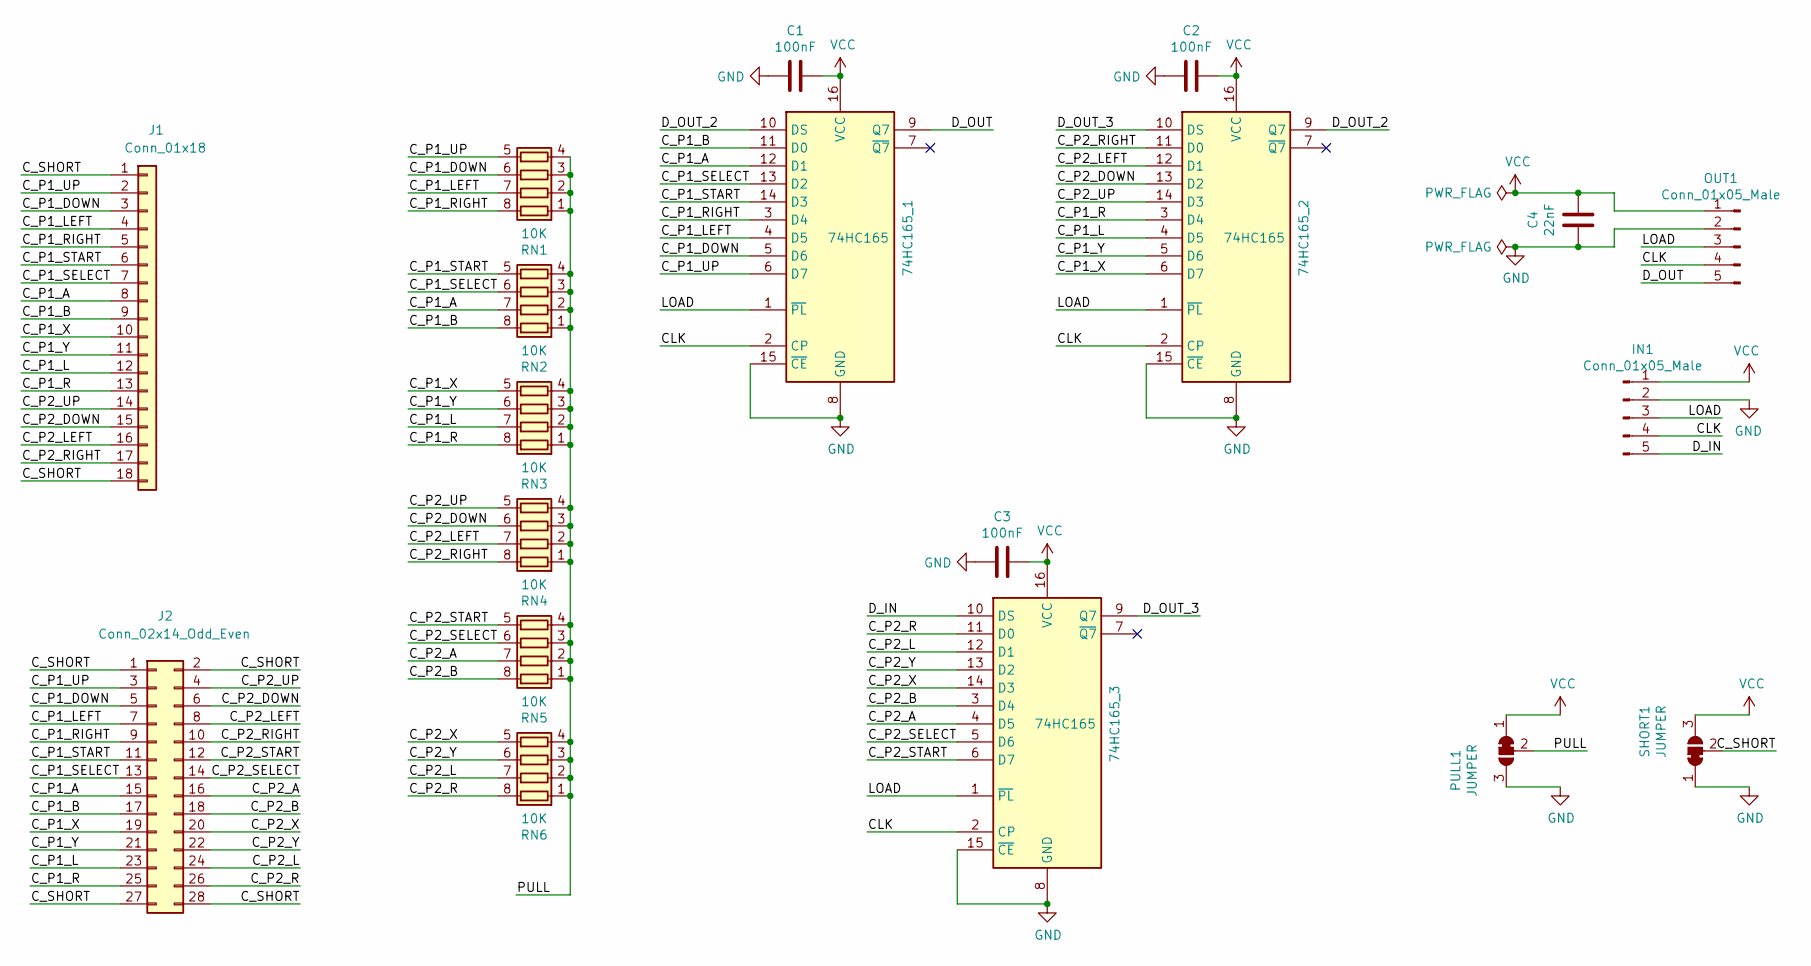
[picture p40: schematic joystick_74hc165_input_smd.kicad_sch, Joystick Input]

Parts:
74HC165_1, 74HC165_2, 74HC165_3: 74HC165; SOIC-16_3.9x9.9mm_P1.27mm
C1, C2, C3: 100nF; C_0805_2012Metric_Pad1.18x1.45mm_HandSolder
C4: 22nF; C_0805_2012Metric_Pad1.18x1.45mm_HandSolder
IN1: Conn_01x05_Male; PinHeader_1x05_P2.54mm_Vertical
J1: Conn_01x18; PinHeader_1x18_P2.54mm_Vertical
J2: Conn_02x14_Odd_Even; PinHeader_2x14_P2.54mm_Vertical
OUT1: Conn_01x05_Male; PinHeader_1x05_P2.54mm_Vertical
PULL1: JUMPER; SolderJumper-3_P1.3mm_Bridged12_Pad1.0x1.5mm_NumberLabels
RN1, RN2, RN3, RN4, RN5, RN6: 10K; R_Array_Concave_4x0603
SHORT1: JUMPER; SolderJumper-3_P1.3mm_Bridged12_Pad1.0x1.5mm_NumberLabels

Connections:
/CLK: 74HC165_1.2 (CP), 74HC165_2.2 (CP), 74HC165_3.2 (CP), IN1.4, OUT1.4
/C_P1_A: 74HC165_1.12 (D1), J1.8, J2.15, RN2.7 (R2.2)
/C_P1_B: 74HC165_1.11 (D0), J1.9, J2.17, RN2.8 (R1.2)
/C_P1_DOWN: 74HC165_1.5 (D6), J1.3, J2.5, RN1.6 (R3.2)
/C_P1_L: 74HC165_2.4 (D5), J1.12, J2.23, RN3.7 (R2.2)
/C_P1_LEFT: 74HC165_1.4 (D5), J1.4, J2.7, RN1.7 (R2.2)
/C_P1_R: 74HC165_2.3 (D4), J1.13, J2.25, RN3.8 (R1.2)
/C_P1_RIGHT: 74HC165_1.3 (D4), J1.5, J2.9, RN1.8 (R1.2)
/C_P1_SELECT: 74HC165_1.13 (D2), J1.7, J2.13, RN2.6 (R3.2)
/C_P1_START: 74HC165_1.14 (D3), J1.6, J2.11, RN2.5 (R4.2)
/C_P1_UP: 74HC165_1.6 (D7), J1.2, J2.3, RN1.5 (R4.2)
/C_P1_X: 74HC165_2.6 (D7), J1.10, J2.19, RN3.5 (R4.2)
/C_P1_Y: 74HC165_2.5 (D6), J1.11, J2.21, RN3.6 (R3.2)
/C_P2_A: 74HC165_3.4 (D5), J2.16, RN5.7 (R2.2)
/C_P2_B: 74HC165_3.3 (D4), J2.18, RN5.8 (R1.2)
/C_P2_DOWN: 74HC165_2.13 (D2), J1.15, J2.6, RN4.6 (R3.2)
/C_P2_L: 74HC165_3.12 (D1), J2.24, RN6.7 (R2.2)
/C_P2_LEFT: 74HC165_2.12 (D1), J1.16, J2.8, RN4.7 (R2.2)
/C_P2_R: 74HC165_3.11 (D0), J2.26, RN6.8 (R1.2)
/C_P2_RIGHT: 74HC165_2.11 (D0), J1.17, J2.10, RN4.8 (R1.2)
/C_P2_SELECT: 74HC165_3.5 (D6), J2.14, RN5.6 (R3.2)
/C_P2_START: 74HC165_3.6 (D7), J2.12, RN5.5 (R4.2)
/C_P2_UP: 74HC165_2.14 (D3), J1.14, J2.4, RN4.5 (R4.2)
/C_P2_X: 74HC165_3.14 (D3), J2.20, RN6.5 (R4.2)
/C_P2_Y: 74HC165_3.13 (D2), J2.22, RN6.6 (R3.2)
/C_SHORT: J1.1, J1.18, J2.1, J2.2, J2.27, J2.28, SHORT1.2 (C)
/D_IN: 74HC165_3.10 (DS), IN1.5
/D_OUT: 74HC165_1.9 (Q7), OUT1.5
/D_OUT_2: 74HC165_1.10 (DS), 74HC165_2.9 (Q7)
/D_OUT_3: 74HC165_2.10 (DS), 74HC165_3.9 (Q7)
/LOAD: 74HC165_1.1 (~PL), 74HC165_2.1 (~PL), 74HC165_3.1 (~PL), IN1.3, OUT1.3
/PULL: PULL1.2 (C), RN1.1 (R1.1), RN1.2 (R2.1), RN1.3 (R3.1), RN1.4 (R4.1), RN2.1 (R1.1), RN2.2 (R2.1), RN2.3 (R3.1), RN2.4 (R4.1), RN3.1 (R1.1), RN3.2 (R2.1), RN3.3 (R3.1), RN3.4 (R4.1), RN4.1 (R1.1), RN4.2 (R2.1), RN4.3 (R3.1), RN4.4 (R4.1), RN5.1 (R1.1), RN5.2 (R2.1), RN5.3 (R3.1), RN5.4 (R4.1), RN6.1 (R1.1), RN6.2 (R2.1), RN6.3 (R3.1), RN6.4 (R4.1)
GND: 74HC165_1.8 (GND), 74HC165_1.15 (~CE), 74HC165_2.8 (GND), 74HC165_2.15 (~CE), 74HC165_3.8 (GND), 74HC165_3.15 (~CE), C1.2, C2.2, C3.2, C4.2, IN1.2, OUT1.2, PULL1.3 (B), SHORT1.1 (A)
VCC: 74HC165_1.16 (VCC), 74HC165_2.16 (VCC), 74HC165_3.16 (VCC), C1.1, C2.1, C3.1, C4.1, IN1.1, OUT1.1, PULL1.1 (A), SHORT1.3 (B)

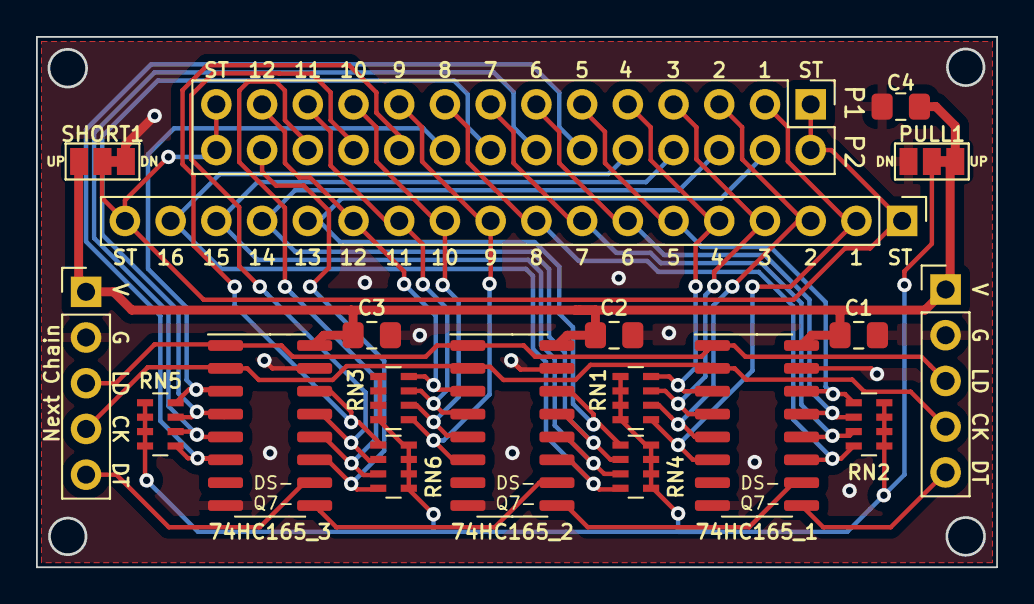
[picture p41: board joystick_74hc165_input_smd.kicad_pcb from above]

Board: 2 copper layers, 53.3 x 29.5 mm, 19 parts (0 on the bottom side), 34 nets.

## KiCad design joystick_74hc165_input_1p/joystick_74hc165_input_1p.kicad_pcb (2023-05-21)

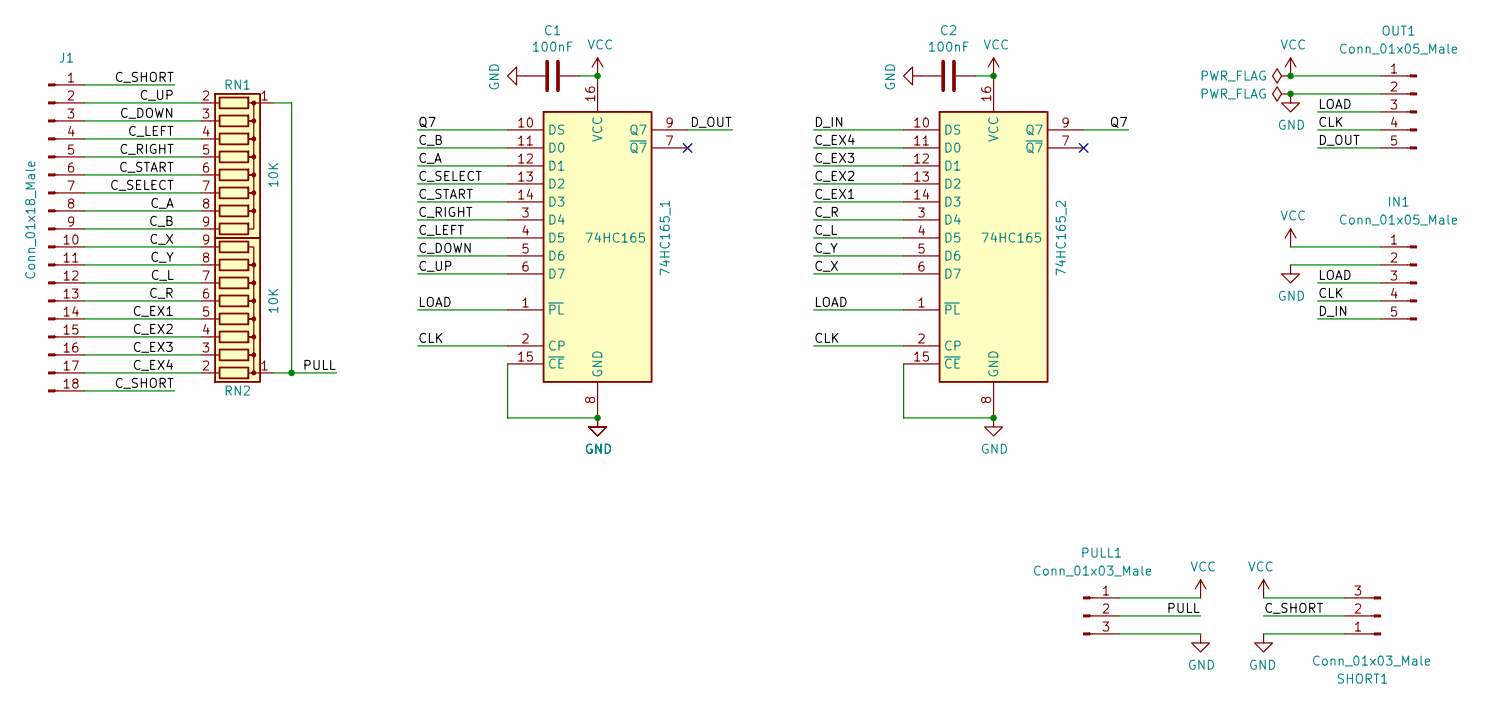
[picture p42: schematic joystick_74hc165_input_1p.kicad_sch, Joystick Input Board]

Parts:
74HC165_1, 74HC165_2: 74HC165; DIP-16_W7.62mm
C1, C2: 100nF; C_Disc_D4.3mm_W1.9mm_P5.00mm
IN1: Conn_01x05_Male; PinHeader_1x05_P2.54mm_Vertical
J1: Conn_01x18_Male; PinHeader_1x18_P2.54mm_Vertical
OUT1: Conn_01x05_Male; PinHeader_1x05_P2.54mm_Vertical
PULL1: Conn_01x03_Male; SolderJumper-3_P1.3mm_Bridged12_Pad1.0x1.5mm_NumberLabels
RN1, RN2: 10K; R_Array_SIP9
SHORT1: Conn_01x03_Male; SolderJumper-3_P1.3mm_Bridged12_Pad1.0x1.5mm_NumberLabels

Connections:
/CLK: 74HC165_1.2 (CP), 74HC165_2.2 (CP), IN1.4, OUT1.4
/C_A: 74HC165_1.12 (D1), J1.8, RN1.8 (R7)
/C_B: 74HC165_1.11 (D0), J1.9, RN1.9 (R8)
/C_DOWN: 74HC165_1.5 (D6), J1.3, RN1.3 (R2)
/C_EX1: 74HC165_2.14 (D3), J1.14, RN2.5 (R4)
/C_EX2: 74HC165_2.13 (D2), J1.15, RN2.4 (R3)
/C_EX3: 74HC165_2.12 (D1), J1.16, RN2.3 (R2)
/C_EX4: 74HC165_2.11 (D0), J1.17, RN2.2 (R1)
/C_L: 74HC165_2.4 (D5), J1.12, RN2.7 (R6)
/C_LEFT: 74HC165_1.4 (D5), J1.4, RN1.4 (R3)
/C_R: 74HC165_2.3 (D4), J1.13, RN2.6 (R5)
/C_RIGHT: 74HC165_1.3 (D4), J1.5, RN1.5 (R4)
/C_SELECT: 74HC165_1.13 (D2), J1.7, RN1.7 (R6)
/C_SHORT: J1.1, J1.18, SHORT1.2
/C_START: 74HC165_1.14 (D3), J1.6, RN1.6 (R5)
/C_UP: 74HC165_1.6 (D7), J1.2, RN1.2 (R1)
/C_X: 74HC165_2.6 (D7), J1.10, RN2.9 (R8)
/C_Y: 74HC165_2.5 (D6), J1.11, RN2.8 (R7)
/D_IN: 74HC165_2.10 (DS), IN1.5
/D_OUT: 74HC165_1.9 (Q7), OUT1.5
/LOAD: 74HC165_1.1 (~PL), 74HC165_2.1 (~PL), IN1.3, OUT1.3
/PULL: PULL1.2, RN1.1 (common), RN2.1 (common)
/Q7: 74HC165_1.10 (DS), 74HC165_2.9 (Q7)
GND: 74HC165_1.8 (GND), 74HC165_1.15 (~CE), 74HC165_2.8 (GND), 74HC165_2.15 (~CE), C1.2, C2.2, IN1.2, OUT1.2, PULL1.3, SHORT1.1
VCC: 74HC165_1.16 (VCC), 74HC165_2.16 (VCC), C1.1, C2.1, IN1.1, OUT1.1, PULL1.1, SHORT1.3

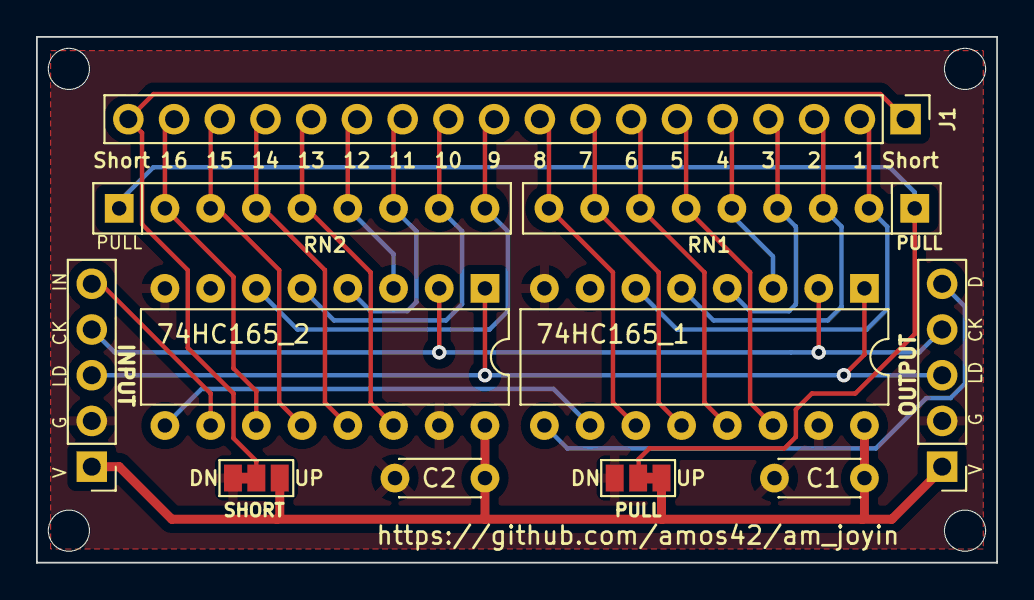
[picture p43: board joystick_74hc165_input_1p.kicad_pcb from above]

Board: 2 copper layers, 53.3 x 29.2 mm, 11 parts (0 on the bottom side), 25 nets.

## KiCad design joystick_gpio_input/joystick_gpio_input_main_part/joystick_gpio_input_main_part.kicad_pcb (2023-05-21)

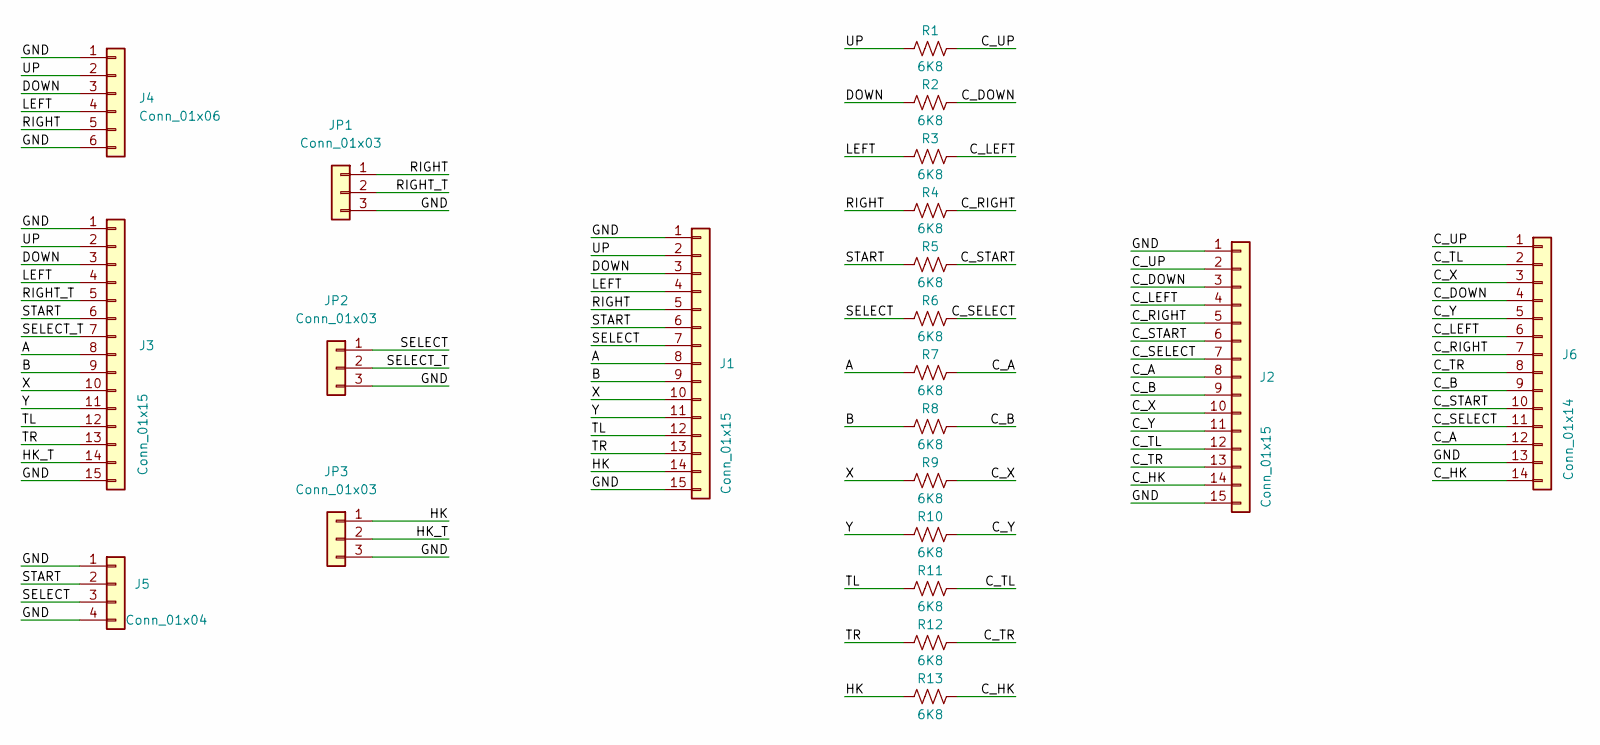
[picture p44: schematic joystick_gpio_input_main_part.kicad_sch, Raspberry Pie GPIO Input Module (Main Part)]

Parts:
J1, J2: Conn_01x15; PinHeader_1x15_P2.54mm_Vertical
J3: Conn_01x15; Molex_PicoBlade_53047-1510_1x15_P1.25mm_Vertical
J4: Conn_01x06; Molex_PicoBlade_53047-0610_1x06_P1.25mm_Vertical
J5: Conn_01x04; Molex_PicoBlade_53047-0410_1x04_P1.25mm_Vertical
J6: Conn_01x14; conn_ex_1x14_P1.25mm_Vertical_Left_Labeled
JP1, JP2, JP3: Conn_01x03; PinHeader_1x03_P2.54mm_Vertical
R1, R2, R3, R4, R5, R6, R7, R8, R9, R10, R11, R12, R13: 6K8; R_0805_2012Metric_Pad1.20x1.40mm_HandSolder

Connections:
/A: J1.8, J3.8, R7.1
/B: J1.9, J3.9, R8.1
/C_A: J2.8, J6.12, R7.2
/C_B: J2.9, J6.9, R8.2
/C_DOWN: J2.3, J6.4, R2.2
/C_HK: J2.14, J6.14, R13.2
/C_LEFT: J2.4, J6.6, R3.2
/C_RIGHT: J2.5, J6.7, R4.2
/C_SELECT: J2.7, J6.11, R6.2
/C_START: J2.6, J6.10, R5.2
/C_TL: J2.12, J6.2, R11.2
/C_TR: J2.13, J6.8, R12.2
/C_UP: J2.2, J6.1, R1.2
/C_X: J2.10, J6.3, R9.2
/C_Y: J2.11, J6.5, R10.2
/DOWN: J1.3, J3.3, J4.3, R2.1
/GND: J1.1, J1.15, J2.1, J2.15, J3.1, J3.15, J4.1, J4.6, J5.1, J5.4, J6.13, JP1.3, JP2.3, JP3.3
/HK: J1.14, JP3.1, R13.1
/HK_T: J3.14, JP3.2
/LEFT: J1.4, J3.4, J4.4, R3.1
/RIGHT: J1.5, J4.5, JP1.1, R4.1
/RIGHT_T: J3.5, JP1.2
/SELECT: J1.7, J5.3, JP2.1, R6.1
/SELECT_T: J3.7, JP2.2
/START: J1.6, J3.6, J5.2, R5.1
/TL: J1.12, J3.12, R11.1
/TR: J1.13, J3.13, R12.1
/UP: J1.2, J3.2, J4.2, R1.1
/X: J1.10, J3.10, R9.1
/Y: J1.11, J3.11, R10.1

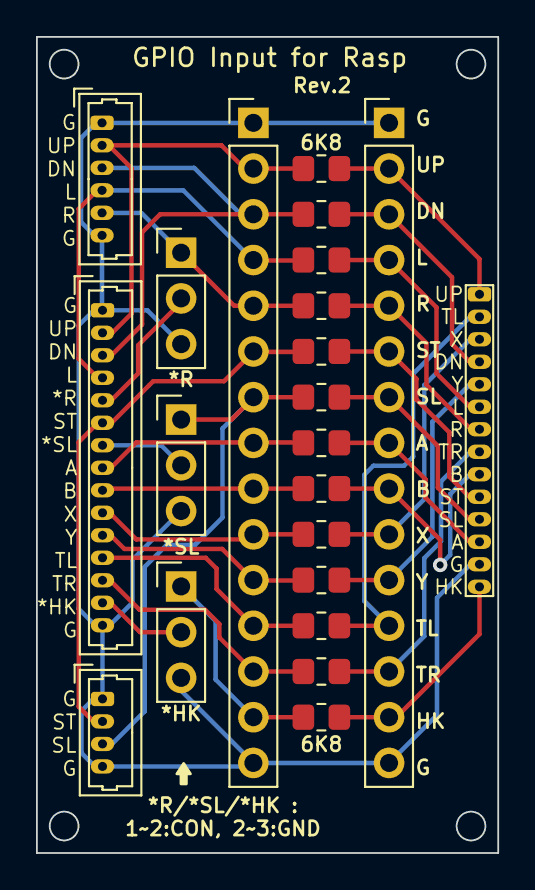
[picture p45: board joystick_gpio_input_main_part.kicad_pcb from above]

Board: 2 copper layers, 25.6 x 45.3 mm, 22 parts (0 on the bottom side), 30 nets.

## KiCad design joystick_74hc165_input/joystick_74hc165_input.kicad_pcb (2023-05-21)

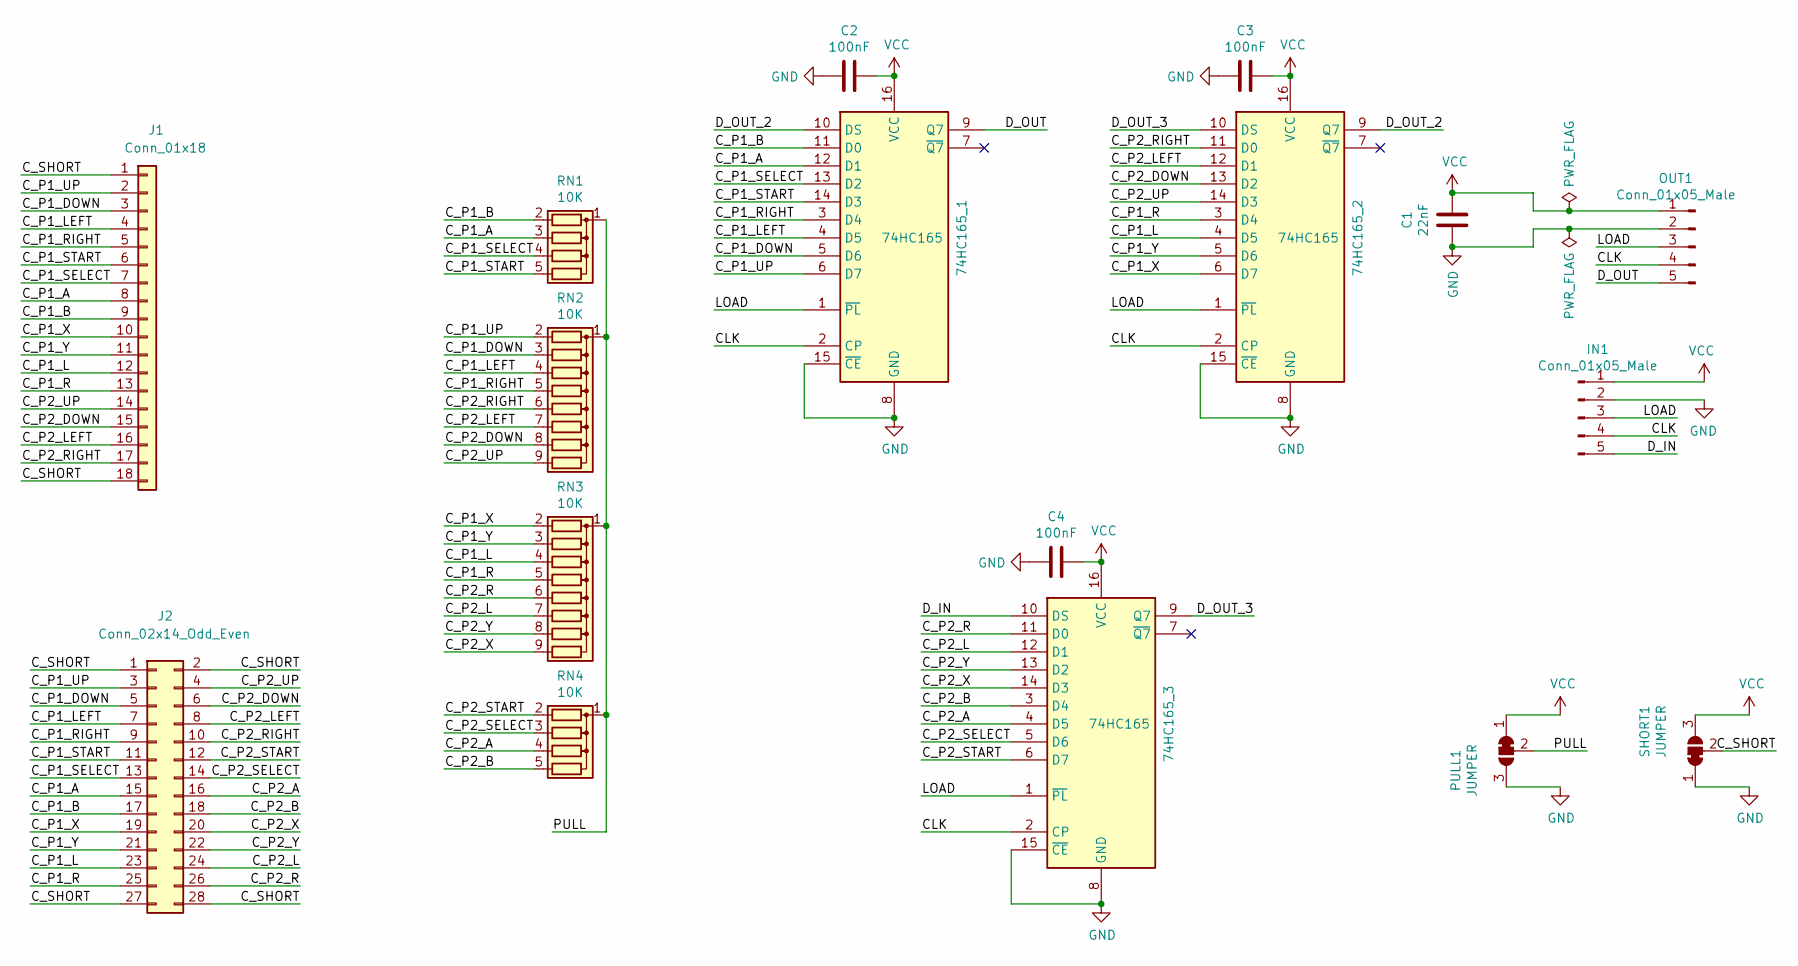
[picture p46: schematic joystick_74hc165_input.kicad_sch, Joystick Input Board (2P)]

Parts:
74HC165_1, 74HC165_2, 74HC165_3: 74HC165; DIP-16_W7.62mm
C1: 22nF; C_0805_2012Metric_Pad1.18x1.45mm_HandSolder
C2, C3, C4: 100nF; C_0805_2012Metric_Pad1.18x1.45mm_HandSolder
IN1: Conn_01x05_Male; PinHeader_1x05_P2.54mm_Vertical
J1: Conn_01x18; PinHeader_1x18_P2.54mm_Vertical
J2: Conn_02x14_Odd_Even; PinHeader_2x14_P2.54mm_Vertical
OUT1: Conn_01x05_Male; PinHeader_1x05_P2.54mm_Vertical
PULL1: JUMPER; SolderJumper-3_P1.3mm_Bridged12_Pad1.0x1.5mm_NumberLabels
RN1, RN4: 10K; R_Array_SIP5
RN2, RN3: 10K; R_Array_SIP9
SHORT1: JUMPER; SolderJumper-3_P1.3mm_Bridged12_Pad1.0x1.5mm_NumberLabels

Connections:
/CLK: 74HC165_1.2 (CP), 74HC165_2.2 (CP), 74HC165_3.2 (CP), IN1.4, OUT1.4
/C_P1_A: 74HC165_1.12 (D1), J1.8, J2.15, RN1.3 (R2)
/C_P1_B: 74HC165_1.11 (D0), J1.9, J2.17, RN1.2 (R1)
/C_P1_DOWN: 74HC165_1.5 (D6), J1.3, J2.5, RN2.3 (R2)
/C_P1_L: 74HC165_2.4 (D5), J1.12, J2.23, RN3.4 (R3)
/C_P1_LEFT: 74HC165_1.4 (D5), J1.4, J2.7, RN2.4 (R3)
/C_P1_R: 74HC165_2.3 (D4), J1.13, J2.25, RN3.5 (R4)
/C_P1_RIGHT: 74HC165_1.3 (D4), J1.5, J2.9, RN2.5 (R4)
/C_P1_SELECT: 74HC165_1.13 (D2), J1.7, J2.13, RN1.4 (R3)
/C_P1_START: 74HC165_1.14 (D3), J1.6, J2.11, RN1.5 (R4)
/C_P1_UP: 74HC165_1.6 (D7), J1.2, J2.3, RN2.2 (R1)
/C_P1_X: 74HC165_2.6 (D7), J1.10, J2.19, RN3.2 (R1)
/C_P1_Y: 74HC165_2.5 (D6), J1.11, J2.21, RN3.3 (R2)
/C_P2_A: 74HC165_3.4 (D5), J2.16, RN4.4 (R3)
/C_P2_B: 74HC165_3.3 (D4), J2.18, RN4.5 (R4)
/C_P2_DOWN: 74HC165_2.13 (D2), J1.15, J2.6, RN2.8 (R7)
/C_P2_L: 74HC165_3.12 (D1), J2.24, RN3.7 (R6)
/C_P2_LEFT: 74HC165_2.12 (D1), J1.16, J2.8, RN2.7 (R6)
/C_P2_R: 74HC165_3.11 (D0), J2.26, RN3.6 (R5)
/C_P2_RIGHT: 74HC165_2.11 (D0), J1.17, J2.10, RN2.6 (R5)
/C_P2_SELECT: 74HC165_3.5 (D6), J2.14, RN4.3 (R2)
/C_P2_START: 74HC165_3.6 (D7), J2.12, RN4.2 (R1)
/C_P2_UP: 74HC165_2.14 (D3), J1.14, J2.4, RN2.9 (R8)
/C_P2_X: 74HC165_3.14 (D3), J2.20, RN3.9 (R8)
/C_P2_Y: 74HC165_3.13 (D2), J2.22, RN3.8 (R7)
/C_SHORT: J1.1, J1.18, J2.1, J2.2, J2.27, J2.28, SHORT1.2 (C)
/D_IN: 74HC165_3.10 (DS), IN1.5
/D_OUT: 74HC165_1.9 (Q7), OUT1.5
/D_OUT_2: 74HC165_1.10 (DS), 74HC165_2.9 (Q7)
/D_OUT_3: 74HC165_2.10 (DS), 74HC165_3.9 (Q7)
/LOAD: 74HC165_1.1 (~PL), 74HC165_2.1 (~PL), 74HC165_3.1 (~PL), IN1.3, OUT1.3
/PULL: PULL1.2 (C), RN1.1 (common), RN2.1 (common), RN3.1 (common), RN4.1 (common)
GND: 74HC165_1.8 (GND), 74HC165_1.15 (~CE), 74HC165_2.8 (GND), 74HC165_2.15 (~CE), 74HC165_3.8 (GND), 74HC165_3.15 (~CE), C1.2, C2.2, C3.2, C4.2, IN1.2, OUT1.2, PULL1.3 (B), SHORT1.1 (A)
VCC: 74HC165_1.16 (VCC), 74HC165_2.16 (VCC), 74HC165_3.16 (VCC), C1.1, C2.1, C3.1, C4.1, IN1.1, OUT1.1, PULL1.1 (A), SHORT1.3 (B)

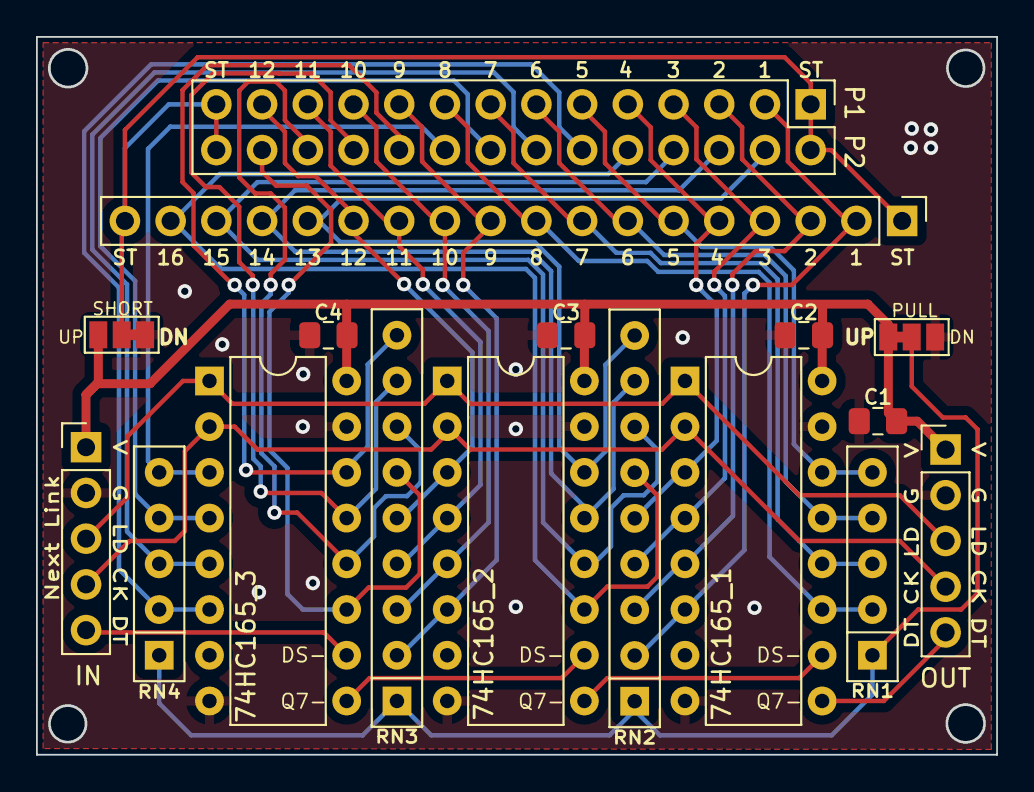
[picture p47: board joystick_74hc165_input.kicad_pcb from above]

Board: 2 copper layers, 53.3 x 39.9 mm, 17 parts (0 on the bottom side), 34 nets.

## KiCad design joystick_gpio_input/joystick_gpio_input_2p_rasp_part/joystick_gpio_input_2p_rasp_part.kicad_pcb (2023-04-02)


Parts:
J1: Conn_02x09_Odd_Even; PinSocket_2x09_P2.54mm_Vertical
J2: Conn_01x13; conn_ex_1x13_P1.25mm_Vertical_Right_Labeled
J3: Conn_01x13; conn_ex_1x13_P1.25mm_Vertical_Left_Labeled

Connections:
/2P_A: J1.18, J2.12, J3.12
/2P_B: J1.16, J2.9, J3.9
/2P_DOWN: J1.7, J2.4, J3.4
/2P_GND: J1.3, J1.8, J1.12, J1.17, J2.13, J3.13
/2P_LEFT: J1.9, J2.6, J3.6
/2P_RIGHT: J1.11, J2.7, J3.7
/2P_SELECT: J1.15, J2.11, J3.11
/2P_START: J1.13, J2.10, J3.10
/2P_TL: J1.2, J2.2, J3.2
/2P_TR: J1.14, J2.8, J3.8
/2P_UP: J1.1, J2.1, J3.1
/2P_X: J1.4, J2.3, J3.3
/2P_Y: J1.10, J2.5, J3.5



Board: 2 copper layers, 11.8 x 23.3 mm, 3 parts (3 on the bottom side), 13 nets.

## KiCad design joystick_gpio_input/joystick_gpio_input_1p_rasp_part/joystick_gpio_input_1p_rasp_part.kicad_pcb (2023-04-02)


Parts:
J1: Conn_02x09_Odd_Even; PinSocket_2x09_P2.54mm_Vertical
J2: Conn_01x14; conn_ex_1x14_P1.25mm_Vertical_Right_Labeled
J3: Conn_01x14; conn_ex_1x14_P1.25mm_Vertical_Left_Labeled

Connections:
/1P_A: J1.16, J2.12, J3.12
/1P_B: J1.12, J2.9, J3.9
/1P_DOWN: J1.5, J2.4, J3.4
/1P_GND: J1.3, J1.8, J1.14, J2.13, J3.13
/1P_HK: J1.17, J2.14, J3.14
/1P_LEFT: J1.7, J2.6, J3.6
/1P_RIGHT: J1.9, J2.7, J3.7
/1P_SELECT: J1.15, J2.11, J3.11
/1P_START: J1.13, J2.10, J3.10
/1P_TL: J1.2, J2.2, J3.2
/1P_TR: J1.10, J2.8, J3.8
/1P_UP: J1.1, J2.1, J3.1
/1P_X: J1.4, J2.3, J3.3
/1P_Y: J1.6, J2.5, J3.5



Board: 2 copper layers, 11.7 x 23.2 mm, 3 parts (3 on the bottom side), 14 nets.

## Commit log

2023-02-12 부품 값 입력
    [joystick_74hc165_input.kicad_pcb, joystick_74hc165_input.kicad_sch, joystick_74hc165_input_1p.kicad_pcb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]
2023-02-12 gpio 입력 보드 점퍼 변경
    [joystick_gpio_input-BOM.csv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]
2023-02-12 gpio input 보드 크기 조정
    [joystick_gpio_input-B_Cu.gbr, joystick_gpio_input-B_Mask.gbr, joystick_gpio_input-B_Paste.gbr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]
2023-02-13 gpio 입력 보드 확장
    [joystick_74hc165_input_jst-B_Cu.gbr, joystick_74hc165_input_jst-B_Mask.gbr, joystick_74hc165_input_jst-B_Silkscreen.gbr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]
2023-03-11 gpio 입력 보드 커넥터 1개씩 늘림
    [joystick_gpio_input-B_Cu.gbr, joystick_gpio_input-B_Mask.gbr, joystick_gpio_input-B_Paste.gbr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]
2023-03-26 Rev 2 설계
    [joystick_gpio_input-B_Cu.gbr, joystick_gpio_input-B_Mask.gbr, joystick_gpio_input-B_Paste.gbr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]
2023-04-01 gpio 입력 보드 개별로 분리
    [joystick_gpio_input-BOM.csv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]
2023-04-01 gpio 입력 보드 미세 조정
    [joystick_gpio_input_1p_rasp_part-B_Cu.gbr, joystick_gpio_input_1p_rasp_part-B_Mask.gbr, joystick_gpio_input_1p_rasp_part-B_Paste.gbr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]
2023-04-02 joystick gpio 스크린샷 추가
    [joystick_gpio_input_1p_rasp_part-B_Cu.gbr, joystick_gpio_input_1p_rasp_part-B_Mask.gbr, joystick_gpio_input_1p_rasp_part-B_Paste.gbr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]
2023-04-02 이미지 링크 교체
2023-04-02 gpio 보드 나사 구멍 미세 조정
    [joystick_gpio_input-CPL.csv, joystick_gpio_input_main_part-B_Cu.gbr, joystick_gpio_input_main_part-B_Mask.gbr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]
2023-05-21 입력 드라이버 주소 마킹
    [joystick_74hc165_input-B_Cu.gbr, joystick_74hc165_input-B_Mask.gbr, joystick_74hc165_input-B_Silkscreen.gbr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]
2023-12-06 gpio 입력시 1p용 핀맵 이미지 추가
2023-12-08 arcade 입력 패널 supoort 보드 추가
    [arcade_input_panel_support-B_Cu.gbr, arcade_input_panel_support-B_Mask.gbr, arcade_input_panel_support-B_Paste.gbr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]
2023-12-10 배선 최적화 및 레이아웃 변경
    [arcade_input_panel_support-B_Cu.gbr, arcade_input_panel_support-B_Mask.gbr, arcade_input_panel_support-B_Paste.gbr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]
2023-12-11 이미지 변경
2023-12-11 문서 보강 (pcb 이미지 추가)
